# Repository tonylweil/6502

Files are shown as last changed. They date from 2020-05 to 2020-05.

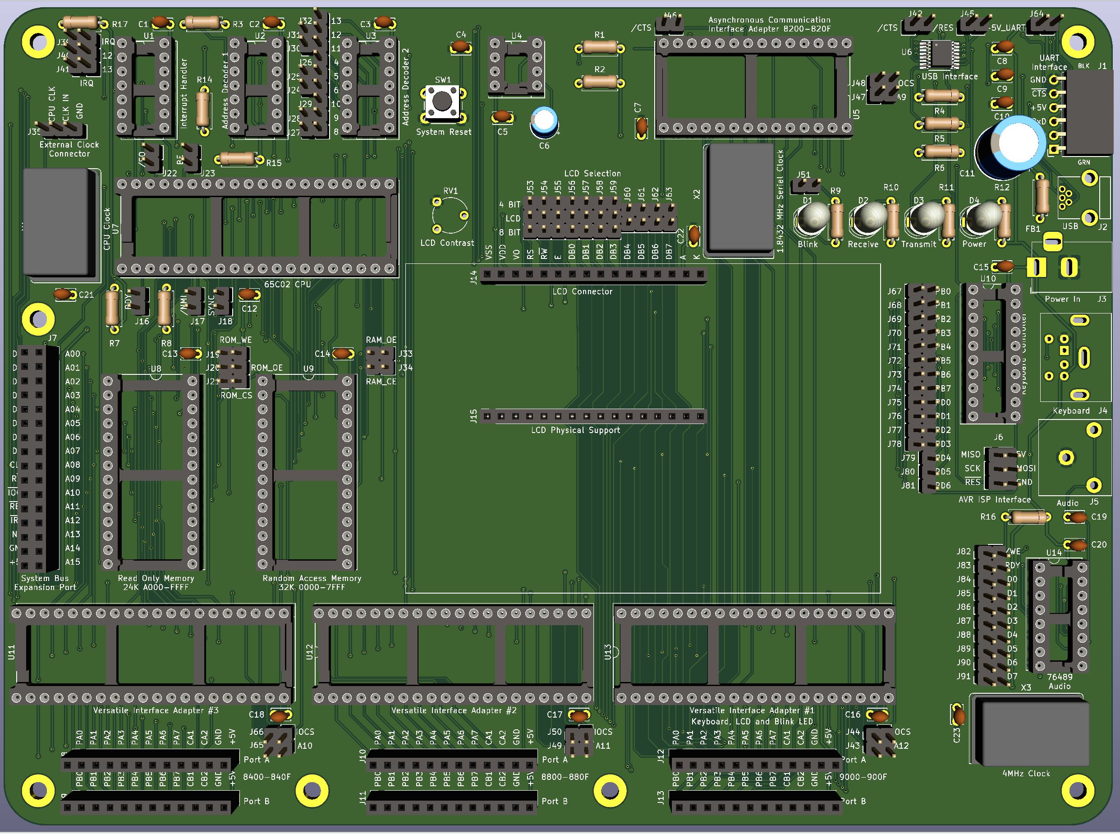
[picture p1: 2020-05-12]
Schematics/65C02_Computer/65C02_Computer.jpg

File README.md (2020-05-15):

# DB6502 V2 Tony Weil's Updates  - 5/15/2020

KiCad Schematics, Board files and Gerbers in the Schematics/65C02_Computer directory have been updated to v002. In general, changes were made to add a sound chip and third VIA. Many jumpers were added allowing disconnecting and reconfiguring many signals. You can use jumpers to switch between LCD 4bit and 8bit wiring. See schematic for all changes.

Changes include:

Added VIA 3 6522

Added 76489 sound chip,  to VIA2, 4Mhz oscillator and Audio Jack

Added Port A and Port B female pin headers for all 3 VIAs

Jumpers on LCD to switch between BE6502 8 bit and DB6502 4 bit, Moved LCD connector to center of board

Jumpers for CPU: BE, SO, NMI, READY, Sync

Jumpers for ROM: /OE, /CE and /WE lines

Jumpers for RAM: /OE and /CE 

Jumpers for VIA1-3 and ACIA, A9-A12 and IOCS Chip Select lines to change hardware addressing

Jumper to ground ACIA /CTS line and FT230x /CTS to support no hardware handshaking

Jumpers added to disconnect any existing connections to VIA1 (LCD and ATTINY) and VIA2 (76489 Sound chip)

Jumpers to be able to use extra NOR gates

FT230X /RES connected to VCCIO with jumper so it doesn't reset USB when computer is reset

Moved Expansion header from center to edge of board

Reorder FTDI header to match dongles, add jumper to disconnect 5v power, changed to horizontal pin header, move to board edge

Changed USB Micro connector to USB Mini THT. Much easier to solder!

Delete USB-B

Added more mounting holes near VIAs and Expansion header to help with plugging in cables

# ==============================

# V1 Readme

# DB6502 - Dawid Buchwald's 6502 Computer

This repository contains all the work in progress during my build of Ben Eater's inspired 6502 8-bit computer similar to typical machines of the early 1980s. If you haven't seen Ben's videos, I would strongly suggest you start there:

[Ben Eater's 6502 project](https://eater.net/6502)

As stated above, this build is not 100% compatible with what Ben had done - and for a reason, described in next section.

If I had to explain shortly "what it is", the answer would be: simple, yet easy to expand, 8-bit CPU based computer designed and built with one goal only: to use it as a learning and tinkering platform to understand how computers really work. You can use it for simple things like understanding buses, clock cycles, instruction execution, but it also demonstrates more complex concepts like interrupts, interfaces to external components and device handling. More on that below. Everything, hopefully, is simple enough to wrap your head around by one person in couple of weeks.

## Why build something different

[Ben's videos](https://www.youtube.com/playlist?list=PLowKtXNTBypFbtuVMUVXNR0z1mu7dp7eH) on 6502 computer are absolutely awesome - it's one of the best sources in the whole Internet explaining how any computer works. The build he introduced is probably sufficient for most of the things you might ever want to build, and yet I decided to deviate from his design.

The rationale behind this project is pretty simple - the best way to test your understanding of certain subject is to try to expand on what you have learned. You never know if you understood something until you test it by introducing changes to original design - and I used this approach in this project to learn a lot. It was my first proper electronics project, so I would like to apologize for any mistakes. If you think something is off or could have been done differently - please go ahead and raise issue for the repo! All improvements are welcome!

## Why would you bother using DB6502 instead of BE6502

Basically, it gives you almost all the flexibility of Ben's buid without the hassle of breadboard connections for the critical components. You can still run all of Ben's programs (using second VIA port), but the days of looking for loose wire between RAM and CPU are over :) You can, obviously, still experiment with peripherals and breadboard connections using extension port and second VIA.

On top of that you get additional features like extra screen (via onboard connector), keyboard for more versatile input and finally all-in-one serial over USB terminal. You also get easy to use software ready to be installed on the machine to jumpstart your tinkering. When using bootloader you don't even have to flash the EEPROM more than once!

**Important note:** All of the content here is, and always will be open source and free to use, and I don't intend to make any profit out of it. The only way I get anything at all (and it's only small commission to be used for future PCBWay orders) is when you order my boards from PCBWay using the links posted below, but you are welcome to grab these gerber files and order the boards from another provider, or even from PCBWay, just by uploading gerbers to your account, if you don't want me to get the commission :)

## What is different

Compared to Ben's 6502 build I introduced the following changes:

1. Added [automatic power-up reset circuitry](Schematics/README.md#automatic-power-on-reset),
2. Changed [address decoder logic](Schematics/README.md#address-decoder-change) (**very important from compatibility perspective**),
3. Changed [LCD interface](Schematics/README.md#lcd-interface-change) from 8-bit to 4-bit (**very important from compatibility perspective**),
4. Added [additional VIA chip](Schematics/README.md#extra-via-chip) to provide easy expansion of the system,
5. Added [ACIA chip for serial communication](Schematics/README.md#extra-acia-chip-for-serial-communication),
6. Added (**optional - more on that later**) [USB-UART interface](Schematics/README.md#extra-usb-uart-interface-chip) for easy connectivity with PC,
7. Added [PS/2 keyboard port and ATtiny4313-based keyboard controller](Schematics/README.md#ps2-keyboard-interface-and-attiny4313-based-controller) to provide proper replacement for five pushbuttons in Ben's design,
8. Added [expansion port](Schematics/README.md#expansion-port) (not really deviation from Ben's build, save for one detail - unlike Ben's build, my version can support various interrupt sources, including the expansion port),
9. Modified [clock module](Schematics/README.md#modified-clock-module) (external),
10. Changed [compilator from VASM to CC65](Schematics/README.md#migration-from-vasm-to-cc65),
11. Added [simple way to choose clock source](Schematics/README.md#clock-input).

You might be wondering if this means that you can't run Ben's programs on DB6502 - and the answer is **YES YOU CAN**. Indeed, some changes to the code are necessary, but thanks to the additional VIA chip and with some changes to the addressing mode you can run any program from Ben's videos. If you want to use LCD in 8-bit mode, you can also use the additional VIA for it, ignoring the built-in LCD connector.

By the way, the opposite is also true - **you can compile and run my programs on Ben's computer**. There are special compilation flags that enable usage of Ben's address decoder. I will describe this in more detail in software section.

Detailed description and rationale for each change is discussed in [Schematics README](Schematics/README.md).

## Getting started

Okay, so it should be pretty clear what this project is about, so how to start playing with it? That really depends on what you decide to do:

- Stick with BE6502 and just use subset of provided software (either to install it in EEPROM, or just use it as reference for your own hacking),
- Build your own breadboard design based on this one with any modifications you can think of,
- Order PCBs of DB6502, solder the components and run provided software to see how it works and get started with your own designs.

To start from scratch it's actually easiest to select last option - after some waiting you will end up having pretty solid base to extend your design on.

### Using provided software with BE6502

If you decide to go down that route, head straight to the `Software` folder, where you will find several programs either identical or similar to what Ben has shown in his videos, but built with much more versatile toolchain.

If you want to read more, go ahead and read [Software folder](Software/README.md) section. Make sure to check out the [building software](Software/README.md#building-software) subsection, as it explains how to compile programs to run on BE6502 directly.

### Build your own breadboard design

Maybe you have already started expanding on Ben's build, or maybe you are just considering it now. If you want to check out how I did certain things, jump right into `Schematics` [folder](Schematics/README.md), where you will find KiCAD projects for all the components used in this project. Obviously the most important one is the `65C02_Computer` project, but there are some additional goodies there.

**Please note:** This part is not very well documented, I have assumed that anybody willing to dig into these schematics already knows how to read them.

Most of the decisions made during the schematic design were explained above. Justification for anything not covered here can be probably found in the [invaluable 6502 primer](http://wilsonminesco.com/6502primer/).

### Using my PCB design

This will be explained in the most detail, obviously. Start with getting [the PCBs](Schematics/README.md#ordering-pcb). **Please note:** clock module is entirely optional, but really useful for single stepping or slow clocking required by Ben Eater's design of Arduino Mega based bus analyzer. As explained in number of places here, you can either order PCBs from PCBWay directly or use your manufacturer of choice - it should have no impact on the final result.

## What's in the repo

Everything, basically. Schematics of the 6502 board, modified clock module, address decoder and other circuits I built during the project. Arduino sketches I used for debugging and simple programs used to test different features.

And, last but not least, full set of sample programs to follow Ben's videos on DB6502 plus my own bootloader/OS. The last two things are coming soon :)

### `Arduino` folder

There are several sketches there, and their full description is available is [separate README](Arduino/README.md).

### `Datasheets` folder

All the datasheets I used when designing DB6502, attached for reference.

### `Schematics` folder

All the KiCAD schematics for the 6502 computer, modified clock module and several others:

- 65C02_Computer - main schematic, including PCB design for DB6502 computer,
- Clock_module - schematic for the modified clock module, including PCB design,
- 555_troubleshoot - schematic of circuit used in [troubleshooting of clock module monostable noise issue](https://www.reddit.com/r/beneater/comments/edp1ls/noise_issue_in_monostable_mode_of_ben_eaters/),
- Address_decoder_basic - schematic of Ben Eater's address decoder for 6502 project,
- Address_decoder_basic_v2 - slightly modified version of the above,
- Address_decoder_extended - schematic of my own address decoder, used in the DB6502 computer.

There is dedicated [README](Schematics/README.md) in the folder, containing all the build-related details.

### `Software` folder

This one is the most important folder, as it contains range of different programs to play with the 6502 computer. Large subset of this programs can be built for Ben Eater's version of the 6502 computer without any changes. Some of them, however, use features available only in DB6502, like ACIA or keyboard connector. These can still be ran on Ben Eater's 6502 computer, assuming that compatible hardware is added to it.

The `Software` folder is currently divided into four main parts:

- `build` - temporary folder where all the build artifacts are created, including ROM binaries to be uploaded to EEPROM,
- `common` - common sources: include files with common constants, sources with shared function, configuration files for different address decoder logic modes, shared makefile used by all projects and small python script to optimize size of loadable modules,
- `rom` - set of projects used to create various ROM images to follow Ben's videos, test different features of the board and **some day** complete operating system for the computer,
- `load` - set of project containing loadable modules. These can be uploaded at runtime, without the need to flash the EEPROM. Basic bootloader is required, obviously, and the usage instructions are provided below.

There is also one "master" makefile located directly in the `Software` folder - it will build all the projects in `rom` and `load` subfolders.

There is dedicated [README](Software/README.md) in the folder, containing all the software-related details.

## Credits

This project would not be possible if not inspiration, support and help from many, many people:

- [Ben Eater](https://eater.net) - his videos inspired me to learn all this,
- [Dirk Grappendorf](https://grappendorf.net) - awesome documentation of his own 6502 project,
- [Wilson Mines Co.](http://wilsonminesco.com) - the best source of 6502-related information,
- [Dane Creek Photography](https://github.com/danecreekphotography) - for all his support and test driving the project,
- [u/transistorykris](https://www.reddit.com/user/transitorykris/) - his [KrisOS](https://github.com/transitorykris/krisos) is a great inspiration for my own OS development,
- [r/beneater community](https://www.reddit.com/r/beneater/) - for all the great ideas, feedback, creative spirit and exceptional support.

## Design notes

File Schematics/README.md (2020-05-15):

# V2 Updates 5/15/2020

Address Mapping Table

The key takeway here is that when porting Ben's programs you have to use this "mapping table":
|Segment|BE6502 |DB6502 v1 |DB6502 v2 |Comment |
|---|---|---|---|---|
|RAM |0x0000-0x3fff|0x0000-0x7fff|0x0000-0x7fff| |
|VIA1 | |0x9000 |0x9000 |Connected to keyboard/LCD/blink LED in my build |
|VIA2 |0x6000 |0x8800 |0x8800|Can be used to run Ben's programs |
|VIA3 | |N/A| 0x8400 ||
|ACIA | |0x8400 | 0x8200 ||
|ROM |0x8000-0xffff|0xa000-0xffff|0xa000-0xffff|**First 8K are not accessible, but need to be burned to the chip**|

# V2 Part Ordering
You can create a Digikey BOM by going to this link:

https://www.digikey.com/BOM/Create/CreateSharedBom?bomId=8248210

Other parts you can't buy from Digikey:

| Reference | Type | Value | Description | Vendor | Part Number |
| --- | --- | --- | --- | --- | --- |
| U5 See Note | IC  | 65C51N | ACIA | Mouser | [W65C51N6TPG–14](https://www.mouser.com/ProductDetail/western-design-center-wdc/w65c51n6tpg-14/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) |
| U5 See Note | IC  | R6551 S6551 | ACIA | Jameco | [6551](https://www.jameco.com/shop/ProductDisplay?catalogId=10001&langId=-1&storeId=10001&productId=43318) |
| U7 | IC  | 65C02 | CPU | Jameco | [W65C02S6TPG-14](https://www.jameco.com/shop/ProductDisplay?productId=2143638) |
| U11, U12, U13 | IC  | 65C22S | VIA | Jameco | [W65C22S6TPG-14](https://www.jameco.com/shop/ProductDisplay?productId=2143591) |
| U14 | IC  | SN76489AN | Audio Chip | Twisty Wrist Arcade  | [SN76489AN](https://www.twistywristarcade.com/sound-processors/1120-sn76489.html)  |

(Copied from v1 notes)

Note: Important note about the ACIA chip: There are basically two types of chips that can be used. 
1) Modern, rated to higher frequencies WDC65C51 and older, 
2) Rockwell 6551P chips, rated only for 1MHz. 

The problem with former is that there is a bug with interrupt handling on transmit operation - both IRQ and status flag polling fail, you have to implement dead loop to wait long enough for the byte to be transmitted. Latter chip is probably no longer manufactured, but can be purchased online from Chinese sellers - these are cheap, but not all of them work correctly, so get more than one to be safe. For me the second chip worked correctly and both polling and IRQ-based transmit work as expected.

# ====================================
# V1 Readme

# 6502 system schematics

This documentation provides all the information regarding my variant of BE6502 computer:

- [Differences between the builds](#deviations-from-ben-eaters-design),
- [Instruction to order the PCBs](#ordering-pcb),
- [Getting started with the PCB](#building-pcb).

## Deviations from Ben Eater's design

This section describes details of each deviation from original BE6502 design.

### Automatic power-on reset

More of a cosmetic thing, but I liked the idea of computer running automatic reset on power-up. The added appeal was that the circuitry is actually copied from the original C64, which makes it instantly 1000x cooler :) You can read more on that here:
[Dirk Grappendorf's 6502 project - RESET](https://www.grappendorf.net/projects/6502-home-computer/reset-circuit.html)

As a side note - I would strongly recommend anybody interested to read about Dirk's project, he has plenty of great insight there!

### Address decoder change

This one was my first _real_ change as in it was _mine_. As Ben explained in his video, there are many ways to handle address decoding logic and he opted for model with 16K RAM, 16K I/O shadow and 32K ROM. He does note that it's a bit of a waste, but given the simplicity of the project it should not be a problem - and he is absolutely right.

That being said, I wanted more for my build. I knew I wanted to be able to load programs into my computer and I wanted to ensure that I provide user with as much RAM as possible. At the same time, I wanted to save some space on more optimized I/O shadow segment. And, most importantly, I wanted to test my understanding of how address decoding works. As stated above, the best way to learn is to change and test your hypothesis. If you want to learn more, I posted thread on [Reddit](https://www.reddit.com/r/beneater/comments/ej3lqi/65c02_address_decoder_for_32k_ram_24k_rom_and_2/) explaining what I did, how I did that and why I know it works. My build provides 32K RAM, 8K I/O shadow (for up to 11 devices), 24K ROM.

The key takeway here is that when porting Ben's programs you have to use this "mapping table":
|Segment|BE6502 |DB6502 |Comment |
|---|---|---|---|
|RAM |0x0000-0x3fff|0x0000-0x7fff| |
|VIA1 | |0x9000 |Connected to keyboard/LCD/blink LED in my build |
|VIA2 |0x6000 |0x8800 |Can be used to run Ben's programs |
|ACIA | |0x8400 | |
|ROM |0x8000-0xffff|0xa000-0xffff|**First 8K are not accessible, but need to be burned to the chip**|

Simplest possible example - [Blink LED example](https://eater.net/downloads/makerom.py) from Ben's page:

```python
#
# Please see this video for details:
# https://www.youtube.com/watch?v=yl8vPW5hydQ
#
code = bytearray([
  0xa9, 0xff,         # lda #$ff
  0x8d, 0x02, 0x60,   # sta $6002

  0xa9, 0x55,         # lda #$55
  0x8d, 0x00, 0x60,   # sta $6000

  0xa9, 0xaa,         # lda #$aa
  0x8d, 0x00, 0x60,   # sta $6000

  0x4c, 0x05, 0x80,   # jmp $8005
  ])

rom = code + bytearray([0xea] * (32768 - len(code)))

rom[0x7ffc] = 0x00
rom[0x7ffd] = 0x80

with open("rom.bin", "wb") as out_file:
  out_file.write(rom)
```

The same program to run on my build:

```python
#
# Please see this video for details:
# https://www.youtube.com/watch?v=yl8vPW5hydQ
#
code = bytearray([
  0xa9, 0xff,         # lda #$ff
  0x8d, 0x02, 0x88,   # sta $8802 # MODIFIED HERE - use different VIA address

  0xa9, 0x55,         # lda #$55
  0x8d, 0x00, 0x88,   # sta $8800 # MODIFIED HERE - use different VIA address

  0xa9, 0xaa,         # lda #$aa
  0x8d, 0x00, 0x88,   # sta $8800 # MODIFIED HERE - use different VIA address

  0x4c, 0x05, 0xa0,   # jmp $a005 # MODIFIED HERE - different code start address, so different jump target
  ])

# MODIFIED BELOW - first 8KB of ROM are not really used, but need to be filled out; actual ROM starts at address
# 0xa000 and is of 24KB length
rom = bytearray([0xea] * 8192) + code + bytearray([0xea] * (24576 - len(code)))

rom[0x7ffc] = 0x00
rom[0x7ffd] = 0xa0 # MODIFIED HERE - different code start address

with open("rom.bin", "wb") as out_file:
  out_file.write(rom)
```

### LCD interface change

One of the silly things I decided to do, was to save pins on the first VIA chip and I decided on the following mapping:

| Port  | Pins | Connection |
| ----- | --- | --- |
| PORTA | CA1,CA2 | Keyboard controller read handshake - for IRQ based communication with keyboard controller |
| PORTA | D0-D7 | Keyboard controller data line - for transferring ASCII scancodes of pressed characters |
| PORTB | CB1,CB2 | Not used, disconnected |
| PORTB | D0 | Blink LED - to be used as the Arduino onboard LED, for easy debugging |
| PORTB | D1-D3 | LCD control signals (register select, R/W, enable) |
| PORTB | D4-D7 | LCD data signals for 4-bit operation |

Afterwards it turned out that 4-bit operation is actually bit more complicated that 8-bit, and it breaks compatibility with Ben's programs. My best advice, if you want to run Ben's LCD programs on this build, is to use the second VIA port and 8-bit interface.

If you want to use onboard LCD conector and 4-bit interface it is suggested to use the code I supplied in this repo. It has all the data communication routines for LCD 4-bit operation tested and ready to go.

### Extra VIA chip

This one increases cost of the build, but in the end you have the whole chip to yourself, so you can hack whatever contraptions you can think of :)

This extra VIA chip can be also used to run Ben's programs, but you have to remember to update addressing mode.

### Extra ACIA chip for serial communication

This one is really important - thanks to ACIA chip you can actually forget about LCD and keyboard altogether, and all the input/output can be handled by the serial port. This also allows you to run programs that are loaded in runtime, over the serial line, making the ROM flashing no longer necessary. Obviously, there is a bootloader program required in ROM and one will be provided in this repo for your use shortly.

Currently my software supports only Rockwell R6551P chips and it uses fully asynchronous, buffered and IRQ driven send/receive operations. In future I plan to add support for WDC65C51 chips, but this requires change in source code to blocking send operation. Not a biggie, just not at the top of my priorities now. More on the ACIA chips below, in the PCB BOM section.

### Extra USB->UART interface chip

When I designed PCB for DB6502, I had one goal in mind: it must be possible to solder it with THT-only components. So, if you don't want to play with SMD soldering (which, admittably, is much easier that it seems), you can completely skip this component and connect serial over one of many UART->USB adapters. The same goes for the Micro-USB port - you can skip it, and use only USB-B port for power. Your call.

If you do decide to use FT230X chip onboard, you will have a 6502 computer that requires only USB cable - simply plug it in your PC, connect using serial terminal and you are good to go, nothing else needed. Power consumption is well below USB limits, even with LCD and external keyboard connected.

### PS/2 Keyboard interface and ATtiny4313 based controller

This was a bit of an overkill with the serial port addition, but I wanted DB6502 to be versatile and enable operation without PC connected.

Software to be uploaded to ATtiny is also provided in this repo and discussed in detail in dedicated section. You can either program the chip away from the board or use the included AVR ISP interface. I have successfully used USBASP programmer onboard, and since the reset lines between ATtiny and CPU/VIA/ACIA/FT230X are all connected, upload operation simply resets the whole computer without any risk for running programs. Pretty neat, that one :)

### Expansion port

The main purpose is to enable easy connection of Arduino-based debugger as used in Ben's videos. Everyone who managed to build the 6502 kit on breadboard knows how difficult it is to manage these connections and prevent them from unplugging system bus wires. In my build there is dedicated connector with several other options.

Beside address bus, data bus, clock and R/W signals, you will also find reset line (can be pulled low for external reset), IRQ input line (can be pulled low to signal interrupt, but can't be used to intercept system IRQs) and IOCS signal from address decoder indicating that CPU is now using address in I/O shadow range.

IOCS line can be used to add additional chips like ACIA or VIA via expansion port. VIA1 is selected using IOCS and A12 line (address 0b1001xxxxxxxxxxxx), VIA2 is selected using IOCS and A11 line (address 0b100x1xxxxxxxxxx), ACIA using IOCS and A10 line (address 0b100xx1xxxxxxxxxx), and you can access external I/O chips using addresses like IOCS and A9 for example (address 0b100xxx1xxxxxxxx). As you can see, it enables up to 8 external I/O chips (last two lines A0/A1 for register select) :)

### Modified clock module

I have also modified Ben's design of clock module used in both [8-bit breadboard computer](https://eater.net/8bit) and in [6502 computer](https://eater.net/6502). The reason here was pretty similar - modification introduced to validate own understanding of the original design. There was another thing, though - contents of my kit were not aligned with Ben's design (wrong kind of switch) and the design itself had serious flaw. Details of both of these things have been explained in detail [here](https://www.reddit.com/r/beneater/comments/eai6ke/issue_with_clock_kit_and_possible_solution_with/) and [here](https://www.reddit.com/r/beneater/comments/edp1ls/noise_issue_in_monostable_mode_of_ben_eaters/).

### Migration from VASM to CC65

As much as I liked VASM for small, simple projects, it became quite cumbersome to use when I wanted to introduce different addressing models. CC65 is basically much better compiler for anything 65(C)02 :)

If time allows, I will also provide special versions of Ben's programs written for VASM, but targeted for my own build.

### Clock input

Clock signal can be provided in one of three ways:

1. Use onboard 1MHz oscillator - simply put jumper on J1 connector two leftmost pins,
2. Use external clock module - remove the jumper from J1 connector, and connect clock signal to middle pin,
3. Use expansion port - remove jumper from J1 connector and provide clock signal via CLK pin of the expansion port.

Last option will be used in (planned currently) custom debugger board.

## Ordering PCB

[First revision of PCBs](https://github.com/dbuchwald/6502/releases/tag/pcb-v001) have been released (one for modified clock module and one for the computer itself). PCBs can be ordered here (**please note: I get small commission in coupons from PCBWay when ordering using these links**. If you don't want that to happen, please download gerbers from the GitHub rulease page and order directly via PCBWay home page):

[PCBWay Shared Projects - 65C02 Hobby Computer](https://www.pcbway.com/project/shareproject/65C02_Hobby_Computer.html)

[PCBWay Shared Projects - Clock Module](https://www.pcbway.com/project/shareproject/Modified_version_of_Clock_Module_by_Ben_Eater_s.html)

### 65C02 Computer Bill Of Materials

The following components are required for DB65C02 Computer

| Reference | Type | Value | Description | Jameco | DigiKey |
| --- | --- | --- | --- | --- | --- |
| C1 | Unpolarized Capacitor  | 100 nF | Disk, 2.5mm raster | [151116](https://www.jameco.com/shop/ProductDisplay?productId=151116) | [399-4151-ND](https://www.digikey.com/products/en?keywords=399-4151-ND) |
| C2 | Unpolarized Capacitor  | 100 nF | Disk, 2.5mm raster | [151116](https://www.jameco.com/shop/ProductDisplay?productId=151116) | [399-4151-ND](https://www.digikey.com/products/en?keywords=399-4151-ND) |
| C3 | Unpolarized Capacitor  | 100 nF | Disk, 2.5mm raster | [151116](https://www.jameco.com/shop/ProductDisplay?productId=151116) | [399-4151-ND](https://www.digikey.com/products/en?keywords=399-4151-ND) |
| C4 | Unpolarized Capacitor  | 100 nF | Disk, 2.5mm raster | [151116](https://www.jameco.com/shop/ProductDisplay?productId=151116) | [399-4151-ND](https://www.digikey.com/products/en?keywords=399-4151-ND) |
| C5 | Unpolarized Capacitor  | 100 nF | Disk, 2.5mm raster | [151116](https://www.jameco.com/shop/ProductDisplay?productId=151116) | [399-4151-ND](https://www.digikey.com/products/en?keywords=399-4151-ND) |
| C6 | Polarized Capacitor | 10 uF | Tube, 2.5mm raster, 5mm diameter | [330692](https://www.jameco.com/shop/ProductDisplay?productId=330692) | [1189-2322-ND](https://www.digikey.com/products/en?keywords=1189-2322-ND) |
| C7 | Unpolarized Capacitor  | 100 nF | Disk, 2.5mm raster | [151116](https://www.jameco.com/shop/ProductDisplay?productId=151116) | [399-4151-ND](https://www.digikey.com/products/en?keywords=399-4151-ND) |
| C8 | Unpolarized Capacitor  | 10 nF | Disk, 2.5mm raster | | [399-4150-ND](https://www.digikey.com/products/en?keywords=399-4150-ND) |
| C9 | Unpolarized Capacitor  | 47 pF | Disk, 2.5mm raster | [2300831](https://www.jameco.com/shop/ProductDisplay?productId=2300831) | [399-9737-ND](https://www.digikey.com/products/en?keywords=399-9737-ND) |
| C10 | Unpolarized Capacitor  | 47 pF | Disk, 2.5mm raster | [2300831](https://www.jameco.com/shop/ProductDisplay?productId=2300831) | [399-9737-ND](https://www.digikey.com/products/en?keywords=399-9737-ND) |
| C11 | Polarized Capacitor | 1000 uF | Tube, 5mm raster, 10mm diameter | [330722](https://www.jameco.com/shop/ProductDisplay?productId=330722) | [1189-1745-ND](https://www.digikey.com/products/en?keywords=1189-1745-ND) |
| C12 | Unpolarized Capacitor  | 100 nF | Disk, 2.5mm raster | [151116](https://www.jameco.com/shop/ProductDisplay?productId=151116) | [399-4151-ND](https://www.digikey.com/products/en?keywords=399-4151-ND) |
| C13 | Unpolarized Capacitor  | 100 nF | Disk, 2.5mm raster | [151116](https://www.jameco.com/shop/ProductDisplay?productId=151116) | [399-4151-ND](https://www.digikey.com/products/en?keywords=399-4151-ND) |
| C14 | Unpolarized Capacitor  | 100 nF | Disk, 2.5mm raster | [151116](https://www.jameco.com/shop/ProductDisplay?productId=151116) | [399-4151-ND](https://www.digikey.com/products/en?keywords=399-4151-ND) |
| C15 | Unpolarized Capacitor  | 100 nF | Disk, 2.5mm raster | [151116](https://www.jameco.com/shop/ProductDisplay?productId=151116) | [399-4151-ND](https://www.digikey.com/products/en?keywords=399-4151-ND) |
| C16 | Unpolarized Capacitor  | 100 nF | Disk, 2.5mm raster | [151116](https://www.jameco.com/shop/ProductDisplay?productId=151116) | [399-4151-ND](https://www.digikey.com/products/en?keywords=399-4151-ND) |
| C17 | Unpolarized Capacitor  | 100 nF | Disk, 2.5mm raster | [151116](https://www.jameco.com/shop/ProductDisplay?productId=151116) | [399-4151-ND](https://www.digikey.com/products/en?keywords=399-4151-ND) |
| D1 | LED | Green | 5mm diameter (PWR) | [2279199](https://www.jameco.com/shop/ProductDisplay?productId=2279199) | [754-1263-ND](https://www.digikey.com/products/en?keywords=754-1263-ND) |
| D2 | LED | Red | 5mm diameter (TX) | [333973](https://www.jameco.com/shop/ProductDisplay?productId=333973) | [754-1264-ND](https://www.digikey.com/products/en?keywords=754-1264-ND) |
| D3 | LED | Green | 5mm diameter (RX) | [2279199](https://www.jameco.com/shop/ProductDisplay?productId=2279199) | [754-1263-ND](https://www.digikey.com/products/en?keywords=754-1263-ND) |
| D4 | LED | Red | 5mm diameter (BLINK) | [333973](https://www.jameco.com/shop/ProductDisplay?productId=333973) | [754-1264-ND](https://www.digikey.com/products/en?keywords=754-1264-ND) |
| FB1 | Ferrite bead small | | | [1844580](https://www.jameco.com/shop/ProductDisplay?productId=1844580) | [490-10997-ND](https://www.digikey.com/products/en?keywords=490-10997-ND) |
| J1 | Pin header 3x1 | | 2.54mm raster | | [2057-PH1-03-UA-ND](https://www.digikey.com/products/en?keywords=2057-PH1-03-UA-ND) |
| J2 | Female pin header 6x1  | | 2.54mm raster | | [S7004-ND](https://www.digikey.com/products/en?keywords=S7004-ND) |
| J3 | USB B Micro | | Molex 105017-0001 | | [WM1399CT-ND](https://www.digikey.com/products/en?keywords=WM1399CT-ND) |
| J4 | USB B | | Standard THT horizontal USB B port | [2096245](https://www.jameco.com/shop/ProductDisplay?productId=2096245) | [2057-USB-B-S-RA-ND](https://www.digikey.com/products/en?keywords=2057-USB-B-S-RA-ND) |
| J5 | Barrel Jack | | Standard power input 2.1/5.5 | [101178](https://www.jameco.com/shop/ProductDisplay?productId=101178) | |
| J6 | Mini-Din-6 | | Standard THT PS/2 Keyboard port | [119475](https://www.jameco.com/shop/ProductDisplay?productId=119475) | [CP-2260-ND](https://www.digikey.com/products/en?keywords=CP-2260-ND) |
| J7 | Female pin header 16x2 | | 2.54mm raster | | [S7049-ND](https://www.digikey.com/products/en?keywords=S7049-ND) |
| J8 | Pin header 3x2 | | AVR ISP 2.54mm raster | | [609-3234-ND](https://www.digikey.com/products/en?keywords=609-3234-ND) |
| J9 | Pin header 12x1 | | 2.54mm raster | | [2057-PH1-12-UA-ND](https://www.digikey.com/products/en?keywords=2057-PH1-12-UA-ND) |
| J10 | Pin header 12x1 | | 2.54mm raster | | [2057-PH1-12-UA-ND](https://www.digikey.com/products/en?keywords=2057-PH1-12-UA-ND) |
| J11 | Female pin header 16x1 | | 2.54mm raster | | [S7049-ND](https://www.digikey.com/products/en?keywords=S7049-ND) |
| R1 | Resistor | 1M | 1/4 watt | [691585](https://www.jameco.com/shop/ProductDisplay?productId=691585) | |
| R2 | Resistor | 47K | 1/4 watt | [691260](https://www.jameco.com/shop/ProductDisplay?productId=691260) | |
| R3 | Resistor | 10K | 1/4 watt | [691104](https://www.jameco.com/shop/ProductDisplay?productId=691104) | |
| R4 | Resistor | 27 | 1/4 watt | [690486](https://www.jameco.com/shop/ProductDisplay?productId=690486) | |
| R5 | Resistor | 27 | 1/4 watt | [690486](https://www.jameco.com/shop/ProductDisplay?productId=690486) | |
| R6 | Resistor | 4K7 | 1/4 watt | [691260](https://www.jameco.com/shop/ProductDisplay?productId=691260) | |
| R7 | Resistor | 4K7 | 1/4 watt | [691260](https://www.jameco.com/shop/ProductDisplay?productId=691260) | |
| R8 | Resistor | 4K7 | 1/4 watt | [691260](https://www.jameco.com/shop/ProductDisplay?productId=691260) | |
| R9 | Resistor | 220 | 1/4 watt | [690700](https://www.jameco.com/shop/ProductDisplay?productId=690700) | |
| R10 | Resistor | 220 | 1/4 watt | [690700](https://www.jameco.com/shop/ProductDisplay?productId=690700) | |
| R11 | Resistor | 220 | 1/4 watt | [690700](https://www.jameco.com/shop/ProductDisplay?productId=690700) | |
| R12 | Resistor | 220 | 1/4 watt | [690700](https://www.jameco.com/shop/ProductDisplay?productId=690700) | |
| R13 | Resistor | 4K7 | 1/4 watt | [691260](https://www.jameco.com/shop/ProductDisplay?productId=691260) | |
| RV1 | Potentiometer | 10K | Piher PT10-LV10-103 | | [1993-1116-ND](https://www.digikey.com/products/en?keywords=1993-1116-ND) |
| SW1 | Pushbutton | | Standard 6mm THT pushbutton | [149948](https://www.jameco.com/shop/ProductDisplay?productId=149948) | |
| U1 | IC | 74HC21 | | [2285255](https://www.jameco.com/shop/ProductDisplay?productId=2285255) | [296-8266-5-ND](https://www.digikey.com/products/en?keywords=296-8266-5-ND) |
| U1 | Socket | 14-pin | | [51626](https://www.jameco.com/shop/ProductDisplay?productId=51626) | [ED90048-ND](https://www.digikey.com/products/en?keywords=ED90048-ND) |
| U2 | IC | 74HC00 | | [45161](https://www.jameco.com/shop/ProductDisplay?productId=45161) | [296-1563-5-ND](https://www.digikey.com/products/en?keywords=296-1563-5-ND) |
| U2 | Socket | 14-pin | | [51626](https://www.jameco.com/shop/ProductDisplay?productId=51626) | [ED90048-ND](https://www.digikey.com/products/en?keywords=ED90048-ND) |
| U3 | IC | 74HC02 | | [45188](https://www.jameco.com/shop/ProductDisplay?productId=45188) | [296-1564-5-ND](https://www.digikey.com/products/en?keywords=296-1564-5-ND) |
| U3 | Socket | 14-pin | | [51626](https://www.jameco.com/shop/ProductDisplay?productId=51626) | [ED90048-ND](https://www.digikey.com/products/en?keywords=ED90048-ND) |
| U4 | IC | NE555 | | [27422](https://www.jameco.com/shop/ProductDisplay?productId=27422) | [296-NE555P-ND](https://www.digikey.com/products/en?keywords=296-NE555P-ND) |
| U1 | Socket | 8-pin | | [51626](https://www.jameco.com/shop/ProductDisplay?productId=51626) | [ED90048-ND](https://www.digikey.com/products/en?keywords=ED90048-ND) |
| U5 | IC | 6551 | ACIA chip, see notes below | [43318](https://www.jameco.com/shop/ProductDisplay?productId=43318) | |
| U6 | IC | FT230XS | | | [768-1135-1-ND](https://www.digikey.com/products/en?keywords=768-1135-1-ND) |
| U7 | IC | 65C02S | | [2143638](https://www.jameco.com/shop/ProductDisplay?productId=2143638) | |
| U7 | Socket | 40-pin | | [41136](https://www.jameco.com/shop/ProductDisplay?productId=41136) | [ED90059-ND](https://www.digikey.com/products/en?keywords=ED90059-ND) |
| U8 | IC | 28C256 | | [74843](https://www.jameco.com/shop/ProductDisplay?productId=74843) | [AT28C256-15PU-ND](https://www.digikey.com/products/en?keywords=AT28C256-15PU-ND) |
| U8 | Socket | 28-pin | Order two | [2289583](https://www.jameco.com/shop/ProductDisplay?productId=2289583) | [ED90520-ND](https://www.digikey.com/products/en?keywords=ED90520-ND) |
| U9 | IC | 62256 | | [82472](https://www.jameco.com/shop/ProductDisplay?productId=82472) | [1450-1480-ND](https://www.digikey.com/products/en?keywords=1450-1480-ND) |
| U9 | Socket | 28-pin | | [2289583](https://www.jameco.com/shop/ProductDisplay?productId=2289583) | [ED90520-ND](https://www.digikey.com/products/en?keywords=ED90520-ND) |
| U10 | IC | ATtiny4313-PU | Add socket | | [ATTINY4313-PU-ND](https://www.digikey.com/products/en?keywords=ATTINY4313-PU-ND) |
| U10 | Socket | 20-pin | | [38623](https://www.jameco.com/shop/ProductDisplay?productId=38623) | [ED90036-ND](https://www.digikey.com/products/en?keywords=ED90036-ND) |
| U11 | IC | 65C22S | | [2143591](https://www.jameco.com/shop/ProductDisplay?productId=2143591) | |
| U11 | Socket | 40-pin | | [41136](https://www.jameco.com/shop/ProductDisplay?productId=41136) | [ED90059-ND](https://www.digikey.com/products/en?keywords=ED90059-ND) |
| U12 | IC | 65C22S | | [2143591](https://www.jameco.com/shop/ProductDisplay?productId=2143591) | |
| U12 | Socket | 40-pin | | [41136](https://www.jameco.com/shop/ProductDisplay?productId=41136) | [ED90059-ND](https://www.digikey.com/products/en?keywords=ED90059-ND) |
| X1 | Crystal Oscillator | 1MHz | | [27861](https://www.jameco.com/shop/ProductDisplay?productId=27861) | [X937-ND](https://www.digikey.com/products/en?keywords=X937-ND) |
| X2 | Crystal Oscillator | 1.8432MHz | | [27879](https://www.jameco.com/shop/ProductDisplay?productId=27879) | [X939-ND](https://www.digikey.com/products/en?keywords=X939-ND) |

[
_Important note about the ACIA chip_: There are basically two types of chips that can be used. Modern, rated to higher frequencies WDC65C51 and older, Rockwell 6551P chips, rated only for 1MHz. The problem with former is that there is a bug with interrupt handling on transmit operation - both IRQ and status flag polling fail, you have to implement dead loop to wait long enough for the byte to be transmitted. Latter chip is probably no longer manufactured, but can be purchased online from Chinese sellers - these are cheap, but not all of them work correctly, so get more than one to be safe. For me the second chip worked correctly and both polling and IRQ-based transmit work as expected.

_Notes about the resistors_: Jameco sells a [resistor assortment](https://www.jameco.com/z/ASST27-R-Resistor-Assortment-1-4-Watt-5-2700-Pieces_10664.html) that includes all the 1/4 watt resistors required for this project except for 27 ohm and will stock you with resistors for many electronics projects going forward.

### Clock Module Bill Of Materials

The following components are required for building Clock Module

| Reference | Type | Value  | Description | Jameco | DigiKey |
| --- | --- | --- | --- | --- | --- |
| C1 | Polarized capacitor | 1 uF | 2.5mm raster, 5mm diameter | [330431](https://www.jameco.com/shop/ProductDisplay?productId=330431) | [1189-1401-ND](https://www.digikey.com/products/en?keywords=1189-1401-ND) |
| C2 | Polarized capacitor | 1 uF | 2.5mm raster, 5mm diameter | [330431](https://www.jameco.com/shop/ProductDisplay?productId=330431) | [1189-1401-ND](https://www.digikey.com/products/en?keywords=1189-1401-ND) |
| C3 | Unpolarized capacitor | 10 nF  | 2.5mm raster | | [399-4150-ND](https://www.digikey.com/products/en?keywords=399-4150-ND) |
| C4 | Unpolarized capacitor | 100 nF | 2.5mm raster | [151116](https://www.jameco.com/shop/ProductDisplay?productId=151116) | [399-4151-ND](https://www.digikey.com/products/en?keywords=399-4151-ND) |
| C5 | Unpolarized capacitor | 100 nF | 2.5mm raster | [151116](https://www.jameco.com/shop/ProductDisplay?productId=151116) | [399-4151-ND](https://www.digikey.com/products/en?keywords=399-4151-ND) |
| C6 | Unpolarized capacitor | 100 nF | 2.5mm raster | [151116](https://www.jameco.com/shop/ProductDisplay?productId=151116) | [399-4151-ND](https://www.digikey.com/products/en?keywords=399-4151-ND) |
| C7 | Unpolarized capacitor | 100 nF | 2.5mm raster | [151116](https://www.jameco.com/shop/ProductDisplay?productId=151116) | [399-4151-ND](https://www.digikey.com/products/en?keywords=399-4151-ND) |
| C8 | Unpolarized capacitor | 100 nF | 2.5mm raster | [151116](https://www.jameco.com/shop/ProductDisplay?productId=151116) | [399-4151-ND](https://www.digikey.com/products/en?keywords=399-4151-ND) |
| C9 | Polarized capacitor | 1 uF | 2.5mm raster, 5mm diameter | [330431](https://www.jameco.com/shop/ProductDisplay?productId=330431) | [1189-1401-ND](https://www.digikey.com/products/en?keywords=1189-1401-ND) |
| D1 | LED | Yellow | 5mm diameter (Automatic tick) | [34825](https://www.jameco.com/shop/ProductDisplay?productId=34825) | [754-1284-ND](https://www.digikey.com/products/en?keywords=754-1284-ND) |
| D2 | LED | Red | 5mm diameter (Manual mode) | [333973](https://www.jameco.com/shop/ProductDisplay?productId=333973) | [754-1264-ND](https://www.digikey.com/products/en?keywords=754-1264-ND) |
| D3 | LED | Green  | 5mm diameter (Automatic mode) | [2279199](https://www.jameco.com/shop/ProductDisplay?productId=2279199) | [754-1263-ND](https://www.digikey.com/products/en?keywords=754-1263-ND) |
| D4 | LED | Yellow | 5mm diameter (Manual tick) | [34825](https://www.jameco.com/shop/ProductDisplay?productId=34825) | [754-1284-ND](https://www.digikey.com/products/en?keywords=754-1284-ND) |
| D5 | LED | Blue | 5mm diameter (Output tick) | [2234071](https://www.jameco.com/shop/ProductDisplay?productId=2234071) | [754-1489-ND](https://www.digikey.com/products/en?keywords=754-1489-ND) |
| J1 | Female pin header 6x1 | | 2.54mm raster | | [S7004-ND](https://www.digikey.com/products/en?keywords=S7004-ND) |
| J2 | Barrel Jack | | Standard power input 2.1/5.5  | [101178](https://www.jameco.com/shop/ProductDisplay?productId=101178) | |
| R1 | Resistor | 1K | 1/4 watt | [690865](https://www.jameco.com/shop/ProductDisplay?productId=690865) | |
| R2 | Resistor | 1K | 1/4 watt | [690865](https://www.jameco.com/shop/ProductDisplay?productId=690865) | |
| R3 | Resistor | 1K | 1/4 watt | [690865](https://www.jameco.com/shop/ProductDisplay?productId=690865) | |
| R4 | Resistor | 100K | 1/4 watt | [691340](https://www.jameco.com/shop/ProductDisplay?productId=691340) | |
| R5 | Resistor | 10K | 1/4 watt | [691260](https://www.jameco.com/shop/ProductDisplay?productId=691260) | |
| R6 | Resistor | 1K | 1/4 watt | [690865](https://www.jameco.com/shop/ProductDisplay?productId=690865) | |
| R7 | Resistor | 10K | 1/4 watt | [691260](https://www.jameco.com/shop/ProductDisplay?productId=691260) | |
| R8 | Resistor | 1K | 1/4 watt | [690865](https://www.jameco.com/shop/ProductDisplay?productId=690865) | |
| R9 | Resistor | 1M | 1/4 watt | [691585](https://www.jameco.com/shop/ProductDisplay?productId=691585) | |
| R10 | Resistor | 220 | 1/4 watt | [690700](https://www.jameco.com/shop/ProductDisplay?productId=690700) | |
| R11 | Resistor | 220 | 1/4 watt | [690700](https://www.jameco.com/shop/ProductDisplay?productId=690700) | |
| R12 | Resistor | 220 | 1/4 watt | [690700](https://www.jameco.com/shop/ProductDisplay?productId=690700) | |
| R13 | Resistor | 220 | 1/4 watt | [690700](https://www.jameco.com/shop/ProductDisplay?productId=690700) | |
| R14 | Resistor | 220 | 1/4 watt | [690700](https://www.jameco.com/shop/ProductDisplay?productId=690700) | |
| R15 | Resistor | 1K | 1/4 watt | [690865](https://www.jameco.com/shop/ProductDisplay?productId=690865) | |
| RV1 | Potentiometer | 1M | Piher PT10-LV10-105 | | [1993-1117-ND](https://www.digikey.com/products/en?keywords=1993-1117-ND) |
| SW1 | Pushbutton | | Standard 6mm THT pushbutton | [149948](https://www.jameco.com/shop/ProductDisplay?productId=149948) | |
| SW2 | Pushbutton | | Standard 6mm THT pushbutton | [149948](https://www.jameco.com/shop/ProductDisplay?productId=149948) | |
| U1 | IC | NE555  | | [27422](https://www.jameco.com/shop/ProductDisplay?productId=27422) | [296-NE555P-ND](https://www.digikey.com/products/en?keywords=296-NE555P-ND) |
| U1 | Socket | 8-pin  | | [51626](https://www.jameco.com/shop/ProductDisplay?productId=51626) | [ED90048-ND](https://www.digikey.com/products/en?keywords=ED90048-ND) |
| U2 | IC | NE555  | | [27422](https://www.jameco.com/shop/ProductDisplay?productId=27422) | [296-NE555P-ND](https://www.digikey.com/products/en?keywords=296-NE555P-ND) |
| U2 | Socket | 8-pin  | | [51626](https://www.jameco.com/shop/ProductDisplay?productId=51626) | [ED90048-ND](https://www.digikey.com/products/en?keywords=ED90048-ND) |
| U3 | IC | NE555  | | [27422](https://www.jameco.com/shop/ProductDisplay?productId=27422) | [296-NE555P-ND](https://www.digikey.com/products/en?keywords=296-NE555P-ND) |
| U3 | Socket | 8-pin  | | [51626](https://www.jameco.com/shop/ProductDisplay?productId=51626) | [ED90048-ND](https://www.digikey.com/products/en?keywords=ED90048-ND) |
| U4 | IC | 74LS04 | | [46316](https://www.jameco.com/shop/ProductDisplay?productId=46316) | [296-1629-5-ND](https://www.digikey.com/products/en?keywords=296-1629-5-ND) |
| U4 | Socket | 14-pin | | [37197](https://www.jameco.com/shop/ProductDisplay?productId=37197) | [ED90049-ND](https://www.digikey.com/products/en?keywords=ED90049-ND) |
| U5 | IC | 74LS32 | | [47466](https://www.jameco.com/shop/ProductDisplay?productId=47466) | [296-1658-5-ND](https://www.digikey.com/products/en?keywords=296-1658-5-ND) |
| U5 | Socket | 14-pin | | [37197](https://www.jameco.com/shop/ProductDisplay?productId=37197) | [ED90049-ND](https://www.digikey.com/products/en?keywords=ED90049-ND) |
| U6 | IC | 74LS08 | | [46375](https://www.jameco.com/shop/ProductDisplay?productId=46375) | [296-1633-5-ND](https://www.digikey.com/products/en?keywords=296-1633-5-ND) |
| U6 | Socket | 14-pin | | [37197](https://www.jameco.com/shop/ProductDisplay?productId=37197) | [ED90049-ND](https://www.digikey.com/products/en?keywords=ED90049-ND) |

## Building PCB

So, let's assume you got the PCBs and all the components, listed in the Bill of Materials. First thing is to solder the components on. At this stage you have to decide if you want to try soldering on the SMD components - there are two, each of them being totally optional. FT230X chip is required if you want to have onboard serial USB->UART converter. MicroUSB connector if you want to use this connector standard. You can replace MicroUSB with standard USB B port (and you can also solder both, as I did, but only use one at a time).

Other optional components are:

- UART Port (J2) - it was placed on the board if you decide to skip the FT230X chip, but you still want to use serial connection. You can use this port to connect to one of external USB->UART converters. **Please note:** if your USB->UART converter doesn't expose CTS/RTS lines, you have to connect CTS and RTS lines permanently to ground,
- USB-B Port (J4) - if you prefer to use Micro-USB port,
- Power-In Port (J5) - you can power the computer using any of the USB ports, so this one is optional,
- PS/2 Connector (J6) - you can skip this one, if you don't intend to connect keyboard. Please note - ATtiny must be connected and programmed even if you don't plan to use keyboard - otherwise the lines would be left floating and could cause strange behavior. You can try grounding them using ATtiny socket, but this has not been tested,
- AVR-ISP Port (J9) - required only if you plan to program the ATtiny onboard, otherwise you can program the chip externally, but it requires chip removal each time,
- Expansion Port (J7) - this one can be skipped, if you don't plan to use Arduino Mega bus analyzer nor any extensions, but it's not recommended.

For the soldering, I would suggest to start with the most difficult components - you will probably get more than one board, so use the first one to brave the SMD components. Important step after soldering is to verify if there are any bridges/shorts between adjacent chip/port pins. Since checking the pins itself might be difficult (they are pretty small), it's easier to check on the connected THT pads, and these are:

| FT230X Pin | Connected THT pad on PCB |
| --- | --- |
| 1 | RxD pad of UART Port (J2) |
| 2 | CTS pad of UART Port (J2) |
| 3 | Bottom pads of resistor R10, R11 |
| 4 | TxD pad of UART Port (J2) |
| 5 | Left pad of capacitor C8 |
| 6 | RTS pad of UART Port (J2) |
| 7 | Disconnected |
| 8 | Left pad of resistor R5 |
| 9 | Left pad of resistor R4 |
| 10 | Bottom pads of resistors R10,R11 |
| 11 | Pad 4 of the ACIA chip (U5) |
| 12 | Right pad of capacitor C8 |
| 13 | Left pad of capacitor C8 |
| 14 | Left pad of LED D3 |
| 15 | Left pad of LED D2 |
| 16 | Disconnected |

| MicroUSB Pin | Connected THT pad on PCB |
| --- | --- |
| 1 | Top pad of ferrite bead FB1 |
| 2 | Right pad of capacitor C10 |
| 3 | Right pad of capacitor C9 |
| 4 | Disconnected |
| 5 | Left pad of capacitors C9, C10 |

So, to verify that there is no bridge between pins 5 and 6 of FT230X, connect your multimeter in circuit continuity mode between left pad of capacitor C8 and RTS pad of UART Port (J2). If it beeps, you have bridge between these two pins and you need to check your soldering again.

Repeat for each pair of adjacent pins. You want to have zero beeps :) Please note: this only means that there are no bridges, it doesn't guarantee that your chip is soldered correctly, that will be verified later.

After SMD components are in place (or if you skipped them), solder on all the THT components, starting from the smallest ones and going up the size. There is plenty of redundant space on the board, so this should be pretty easy. Make sure to observe polarity of capacitors and LEDs and be careful when mounting ACIA chip - it's actually oriented differently than the rest of horizontal chips on the board.

After all the components are soldered in place, put the chips in sockets (I recommend using two tooled sockets for ROM - one will be soldered to the board, the other one will be used for easy ROM replacement for programming) and check everything once again - orientation of the chips, visible solder bridges, etc. If it looks good, connect power and you expect the power LED to light up. If this works, go to next step, would be building, installing and running sample programs. This is all covered in [Software documentation](../Software/README.md)

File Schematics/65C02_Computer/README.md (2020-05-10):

Schematics, PCB and Gerbers updates to v002

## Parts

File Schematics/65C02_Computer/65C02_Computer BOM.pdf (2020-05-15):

17 0.1uF | Unpolarized capacitor | https://www.digikey.com/products/en?keywords=399-4151-ND | C1-C5, C7, C12-C18, C20-C23, | Digikey 1 10uF | Polarized capacitor | https://www.digikey.com/products/en?keywords=1189-2322-ND | C6, | Digikey 1 10nF | Unpolarized capacitor | https://www.digikey.com/products/en?keywords=399-4150-ND | C8, | Digikey 2 47pF | Unpolarized capacitor | https://www.digikey.com/products/en?keywords=399-9737-ND | C9, C10, | Digikey 1 1000uF | Polarized capacitor | https://www.digikey.com/products/en?keywords=1189-1745-ND | C11, | Digikey 1 1uf | Unpolarized capacitor | https://www.digikey.com/product-detail/en/kemet/C320C105K5N5TA91707301/399-14394-1-ND/6919016 C19, | Digikey 1 5mm LED Green | Light emitting diode | https://www.digikey.com/products/en?keywords=754-1263-ND | D1, D3 | Digikey 1 | 5mm LED Red | Light emitting diode | https://www.digikey.com/products/en?keywords=754-1264-ND | D2, D4 | Digikey 1 | Ferite bead | Ferrite bead | https://www.digikey.com/products/en?keywords=490-10997-ND | FB1, | Digikey 1 | 1x6 right angle header | FTDI UART Connector | https://www.digikey.com/product-detail/en/w%C3%BCrth-elektronik/61300611021/732-5339-ND/4846832 J1, | Digikey 1 | USB Mini Jack | USB Mini Type B connector | https://www.digikey.com/product-detail/en/te-connectivity-amp-connectors/1734510-1/A107788-ND/4021669 J2, | Digikey 1 | DC Barrel Jack | Power Connector | https://www.digikey.com/product-detail/en/cui-devices/PJ-102AH/CP-102AH-ND/408448 | J3, | Digikey 1 | Mini-DIN-6 | Mini-DIN-6 Keyboard Connector | https://www.digikey.com/products/en?keywords=CP-2260-ND | J4, | Digikey 1 | SJ1-3523N Audio Jack | Audio Jack, 3 Poles (Stereo / TRS) | https://www.digikey.com/product-detail/en/cui-devices/SJ1-3523N/CP1-3523N-ND/738689 | J5, | Digikey 1 | 6 pin AVR ISP | Atmel 6-pin ISP connector | https://www.digikey.com/products/en?keywords=609-3234-ND | J6, | Digikey 1 | 2x16 female header | Expansion Port | https://www.digikey.com/product-detail/en/sullins-connector-solutions/PPPC162LFBN-RC/S7119-ND/810255 J7, | Digikey 6 | 1x12 female header | VIA Ports | https://www.digikey.com/product-detail/en/sullins-connector-solutions/PPPC121LFBN-RC/S7045-ND/810184 J8-J13 | Digikey 2 | 1x16 female header | LCD Connector | https://www.digikey.com/product-detail/en/sullins-connector-solutions/PPPC161LFBN-RC/S7049-ND/810188 J14-J15 | Digikey 10 | 2x 12 male pinr header | cut for 2 pin male headers | https://www.digikey.com/product-detail/en/amphenol-icc-fci/67997-112HLF/609-3227-ND/1878550 J16-18 22-25 27-28 30-31 33-37 39-51 60-78 82-91 | Digikey 1 | 1 pin male header | cut for 1 pin male headers | https://www.digikey.com/product-detail/en/amphenol-icc-fci/68001-212HLF/609-3280-ND/1878537 J26, J29, J32, J79, J80, J81, | Digikey 1 | 3x7 male header | Combined for 7, 1x3 LCD jumpers | https://www.digikey.com/product-detail/en/samtec-inc/TSW-107-07-L-T/TSW-107-07-L-T-ND/7867706J53, J54, J55, J56, J57, J58, J59, | Digikey 1 | 1M ohm | Resistor | https://www.digikey.com/product-detail/en/stackpole-electronics-inc/CF14JT1M00/CF14JT1M00CT-ND/1830423 R1, | Digikey 1 | 47k ohm | Resistor | https://www.digikey.com/product-detail/en/stackpole-electronics-inc/RC14JT47K0/RC14JT47K0CT-ND/10127355 R2, | Digikey 1 | 10k ohm | Resistor | https://www.digikey.com/product-detail/en/stackpole-electronics-inc/CF14JT10K0/CF14JT10K0CT-ND/1830374 R3, | Digikey 2 | 27 ohm | Resistor | https://www.digikey.com/product-detail/en/stackpole-electronics-inc/CF14JT27R0/CF14JT27R0CT-ND/1830313 R4, R5, | Digikey 6 | 3.3k ohm | Resistor | https://www.digikey.com/product-detail/en/stackpole-electronics-inc/CF14JT3K30/CF14JT3K30CT-ND/1830362 R6, R7, R8, R14, R15, R17, | Digikey 4 | 270 ohm | Resistor | https://www.digikey.com/product-detail/en/stackpole-electronics-inc/CF14JT270R/CF14JT270RCT-ND/1830336 R9, R10, R11, R12, | Digikey 1 | 1k ohm | Resistor | https://www.digikey.com/product-detail/en/stackpole-electronics-inc/CF14JT1K00/CF14JT1K00CT-ND/1830350 R16, | Digikey 1 | 10k trimpot Piher_PT-6-V | Potentiometer | https://www.digikey.com/product-detail/en/amphenol-piher-sensing-systems/PT6MV-103A2020/1993-1052-ND/9555890 RV1, | Digikey 1 | Standard pushbutton 6mm | Push button switch | https://www.digikey.com/product-detail/en/te-connectivity-alcoswitch-switches/1825910-6/450-1650-ND/1632536 SW1, | Digikey 1 | 74HC21 | Dual 4-input AND | https://www.digikey.com/products/en?keywords=296-8266-5-ND | U1, | Digikey 1 | 74HC00 | quad 2-input NAND gate | https://www.digikey.com/products/en?keywords=296-1563-5-ND | U2, | Digikey 1 | 74HC02 | quad 2-input NOR gate | https://www.digikey.com/products/en?keywords=296-1564-5-ND | U3, | Digikey 1 | NE555 | Precision Timers, DIP-8/SOIC-8 | https://www.digikey.com/products/en?keywords=296-NE555P-ND | U4, | Digikey 1 | R6551 | See Note Below: | https://www.jameco.com/shop/ProductDisplay?catalogId=10001&langId=-1&storeId=10001&productId=43318 U5, | Jameco
1 | 65C51N | See Note Below: (Out of stock?) | http://www.westerndesigncenter.com/wdc/w65c51n-chip.cfm | U5, | WDC
1 | FT230XS | USB SERIAL BASIC UART | https://www.digikey.com/products/en?keywords=768-1135-1-ND | U6, | Digikey 1 | 65C02S | MPU 8-Bit 14MHz | https://www.jameco.com/shop/ProductDisplay?productId=2143638 | U7, | Jameco
1 | 28C256 EEPROM | EEPROM 256K (Get Extra to swap EEPROM) | https://www.digikey.com/products/en?keywords=AT28C256-15PU-ND | U8, | Digikey 1 | 62256 RAM | SRAM 256K | https://www.digikey.com/products/en?keywords=1450-1480-ND | U9, | Digikey 1 | ATtiny4313-PU | MCU 8BIT 4KB | https://www.digikey.com/products/en?keywords=ATTINY4313-PU-ND | U10, | Digikey 3 | 65C22S VIA | Versatile Interface Adapter | https://www.jameco.com/shop/ProductDisplay?productId=2143591 | U11, U12, U13, | Jameco
1 | SN76489AN | Audi Chip | https://www.twistywristarcade.com/search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 U14, | Twist Wrist Arcade
1 | 1 MHz | XTAL OSC XO 1.0000MHZ | https://www.digikey.com/products/en?keywords=ECS-100AX-010 | X1, | Digikey 1 | 1.8432 MHz | XTAL OSC XO 1.8432MHZ | https://www.digikey.com/products/en?keywords=ECS-100AX-018 | X2, | Digikey 1 | 4 MHz | TAL OSC XO 4.0000MHZ | https://www.digikey.com/products/en?keywords=ECS-100AX-040 | X3, | Digikey 3 | DIP 14 x7mm socket | https://www.digikey.com/products/en?keywords=110-44-314-41-001000 | U1-U3 | Digikey 1 | DIP 8 x7mm socket | https://www.digikey.com/products/en?keywords=110-44-308-41-001000 | U4, | Digikey 1 | DIP 16 x7mm socket | https://www.digikey.com/products/en?keywords=110-44-316-41-001000 | U14, | Digikey 1 | DIP 20 x7mm socket | https://www.digikey.com/products/en?keywords=110-44-320-41-001000 | U10, | Digikey 2 | DIP 28 x7mm socket | Get extra to swap EEPROM | https://www.digikey.com/products/en?keywords=110-44-628-41-001000 | U8-U9 | Digikey 4 | DIP 40 x15mm socket | https://www.digikey.com/products/en?keywords=110-44-640-41-001000 | U7, U11-U13 | Digikey 3 | DIP 14 x7mm Oscillator sockets | https://www.digikey.com/product-detail/en/aries-electronics/1107741/A462-ND/261894 | X1, X2, X3 | Digikey 50 | 2 pin jumpers | https://www.digikey.com/product-detail/en/sullins-connector-solutions/SPC02SYAN/S9001-ND/76375Jumpers | Digikey

Notes: Some references were deleted from the schematic and not added back

[ Important note about the ACIA chip: There are basically two types of chips that can be used. Modern, rated to higher frequencies WDC65C51 and older, Rockwell 6551P chips, rated only for 1MHz. The problem with former is that there is a bug with interrupt handling on transmit operation - both IRQ and status flag polling fail, you have to implement dead loop to wait long enough for the byte to be transmitted. Latter chip is probably no longer manufactured, but can be purchased online from Chinese sellers - these are cheap, but not all of them work correctly, so get more than one to be safe. For me the second chip worked correctly and both polling and IRQ-based transmit work as expected.

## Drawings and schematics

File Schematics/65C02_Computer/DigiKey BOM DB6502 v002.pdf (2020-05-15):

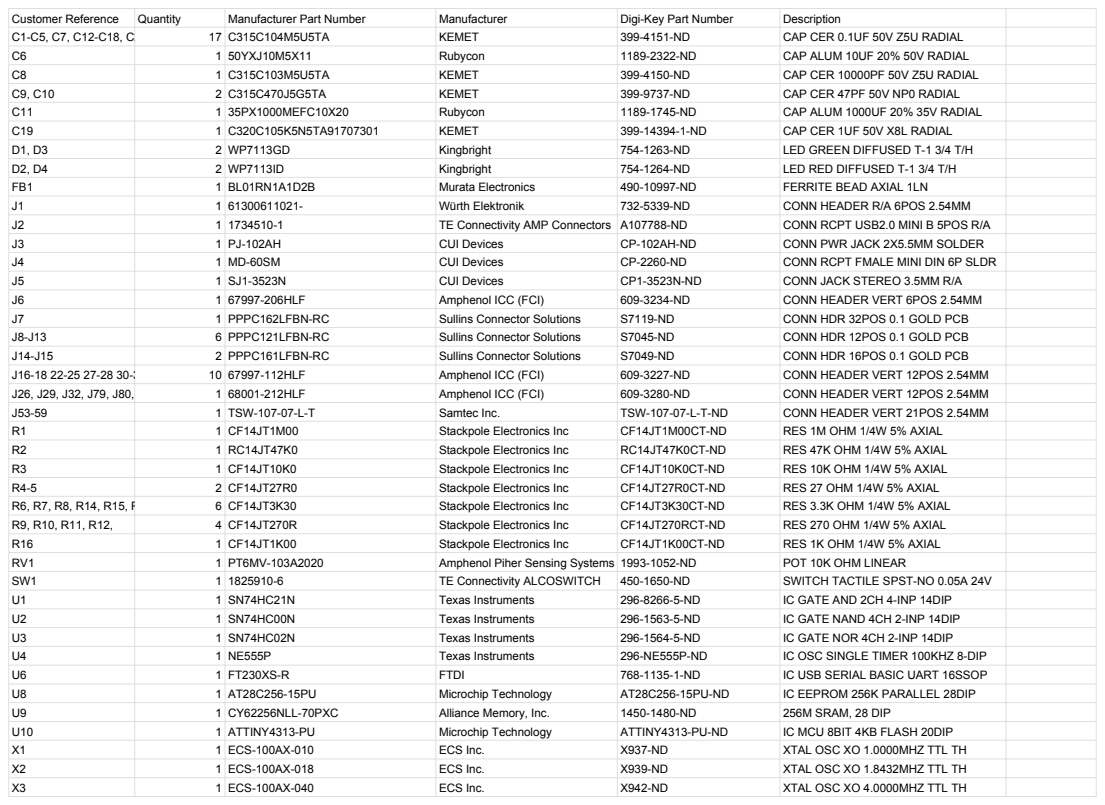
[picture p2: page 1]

U1-3 | 3 | 110-44-314-41-001000 | Mill-Max Manufacturing Corp. | ED90049-ND | CONN IC DIP SOCKET 14POS TIN
U4 | 1 | 110-44-308-41-001000 | Mill-Max Manufacturing Corp. | ED90048-ND | CONN IC DIP SOCKET 8POS TIN
U5,U8-9 | 3 | 110-44-628-41-001000 | Mill-Max Manufacturing Corp. | ED90057-ND | CONN IC DIP SOCKET 28POS TIN
U7, U11-13 | 4 | 110-44-640-41-001000 | Mill-Max Manufacturing Corp. | ED90059-ND | CONN IC DIP SOCKET 40POS TIN
U10 | 1 | 110-44-320-41-001000 | Mill-Max Manufacturing Corp. | ED90052-ND | CONN IC DIP SOCKET 20POS TIN
U14 | 1 | 110-44-316-41-001000 | Mill-Max Manufacturing Corp. | ED90050-ND | CONN IC DIP SOCKET 16POS TIN
X1-3 | 3 | 1107741- | Aries Electronics | A462-ND | OSCILLATOR SOCKET FULL SIZE 4PIN
Jumpers | 50 | SPC02SYAN | Sullins Connector Solutions | S9001-ND | CONN JUMPER SHORTING GOLD FLASH

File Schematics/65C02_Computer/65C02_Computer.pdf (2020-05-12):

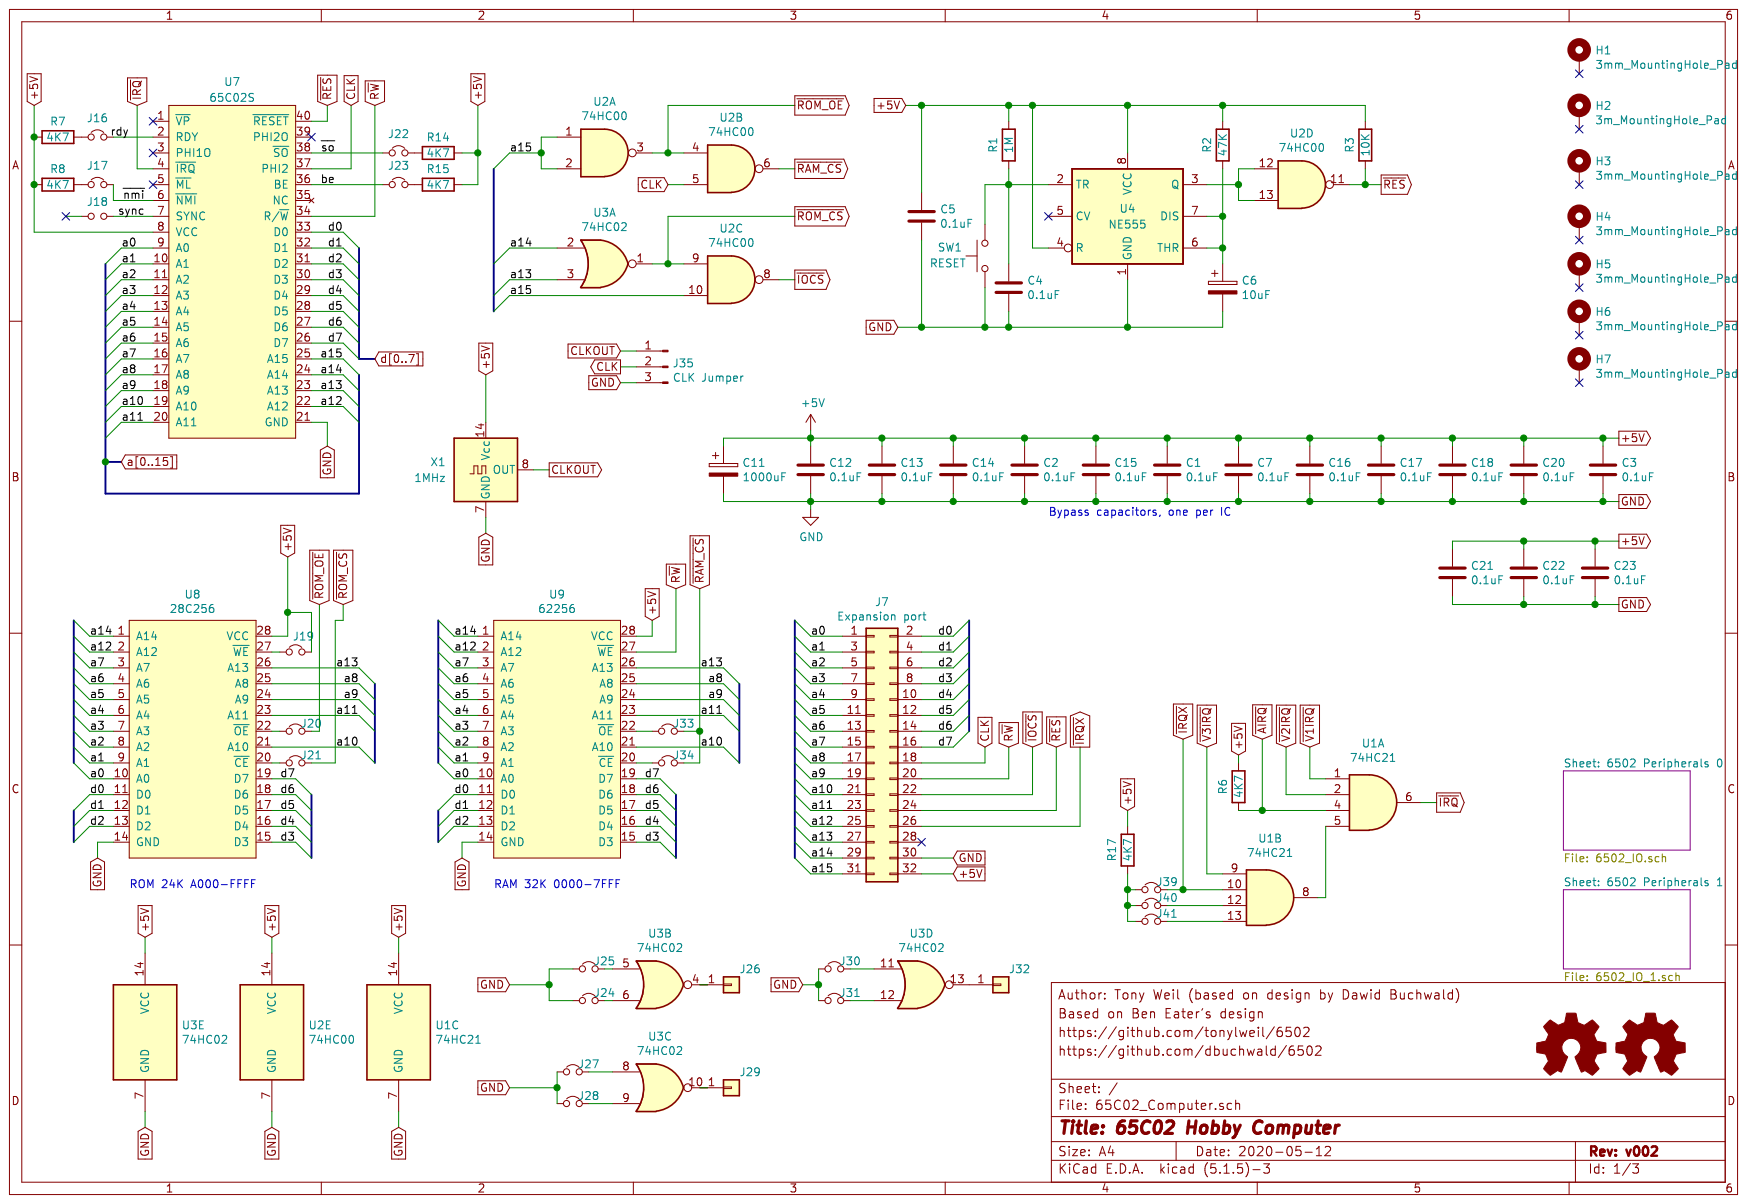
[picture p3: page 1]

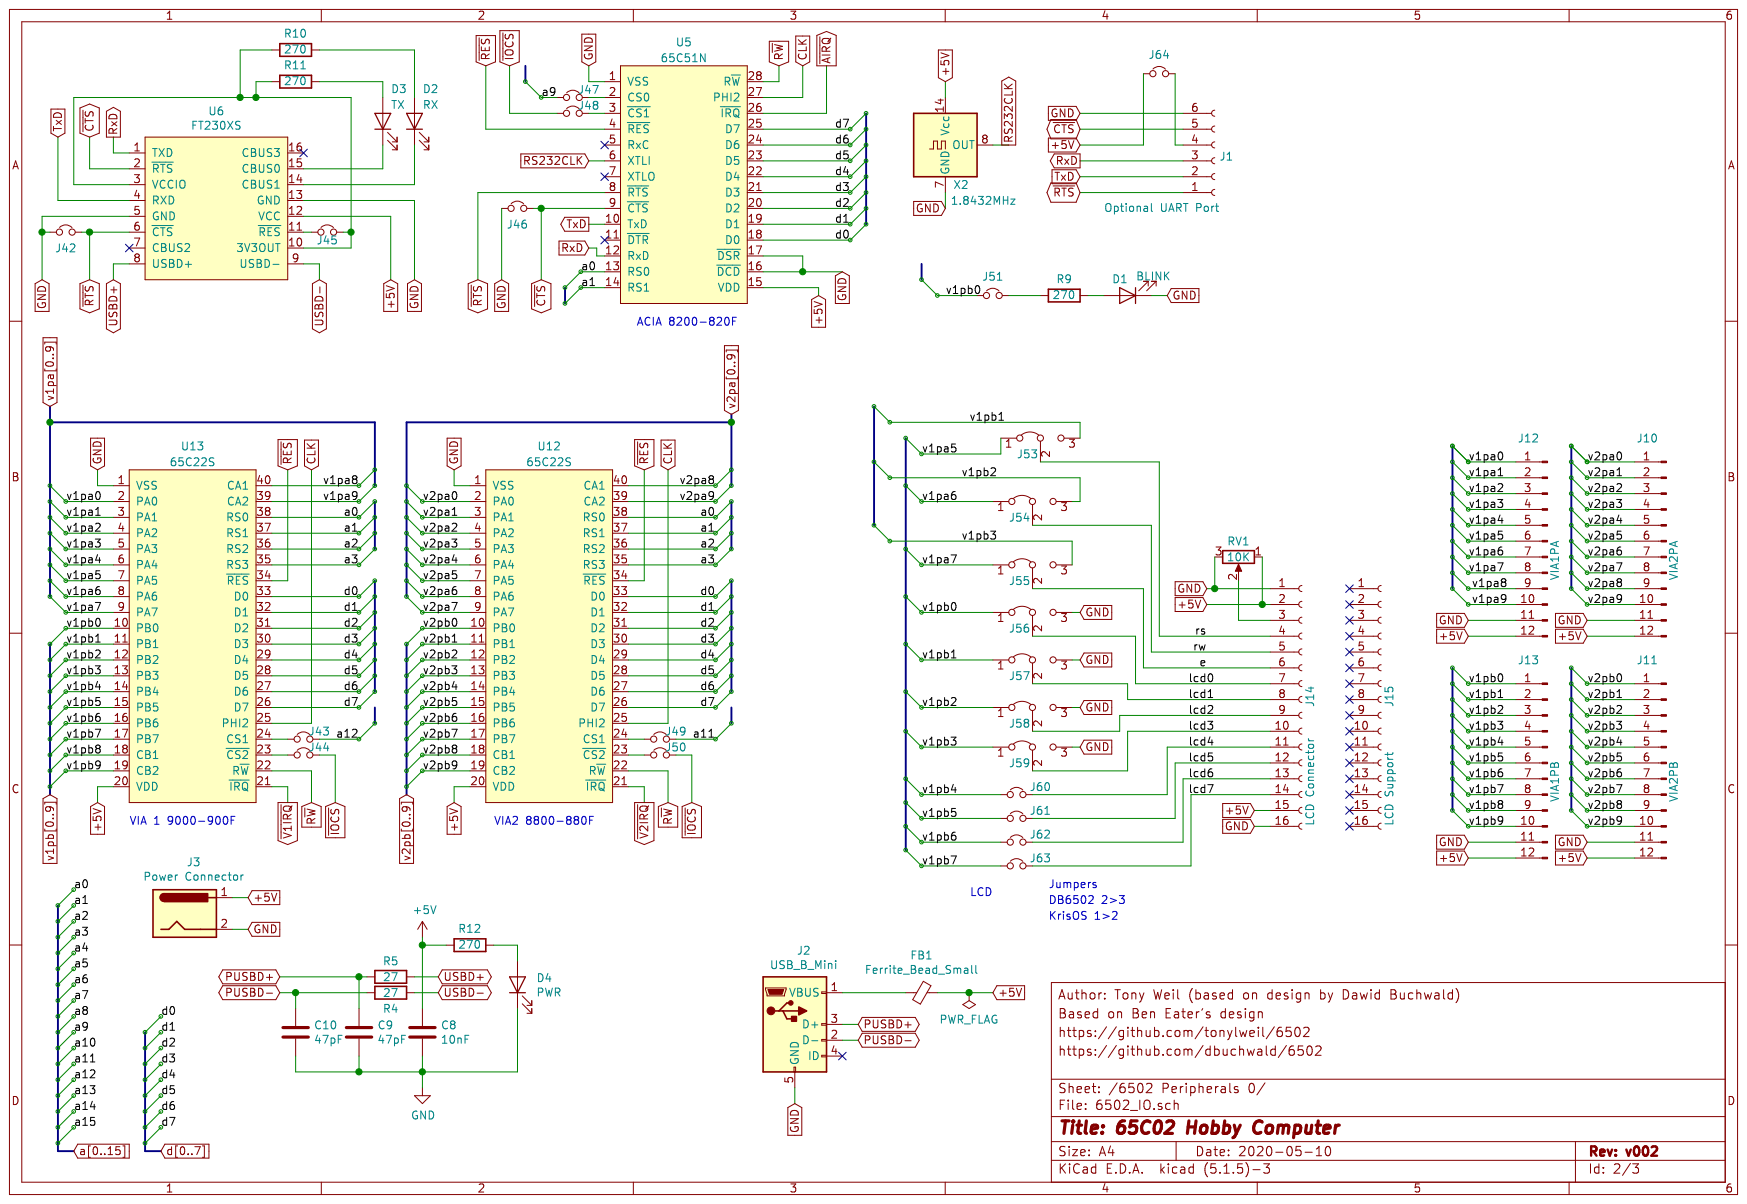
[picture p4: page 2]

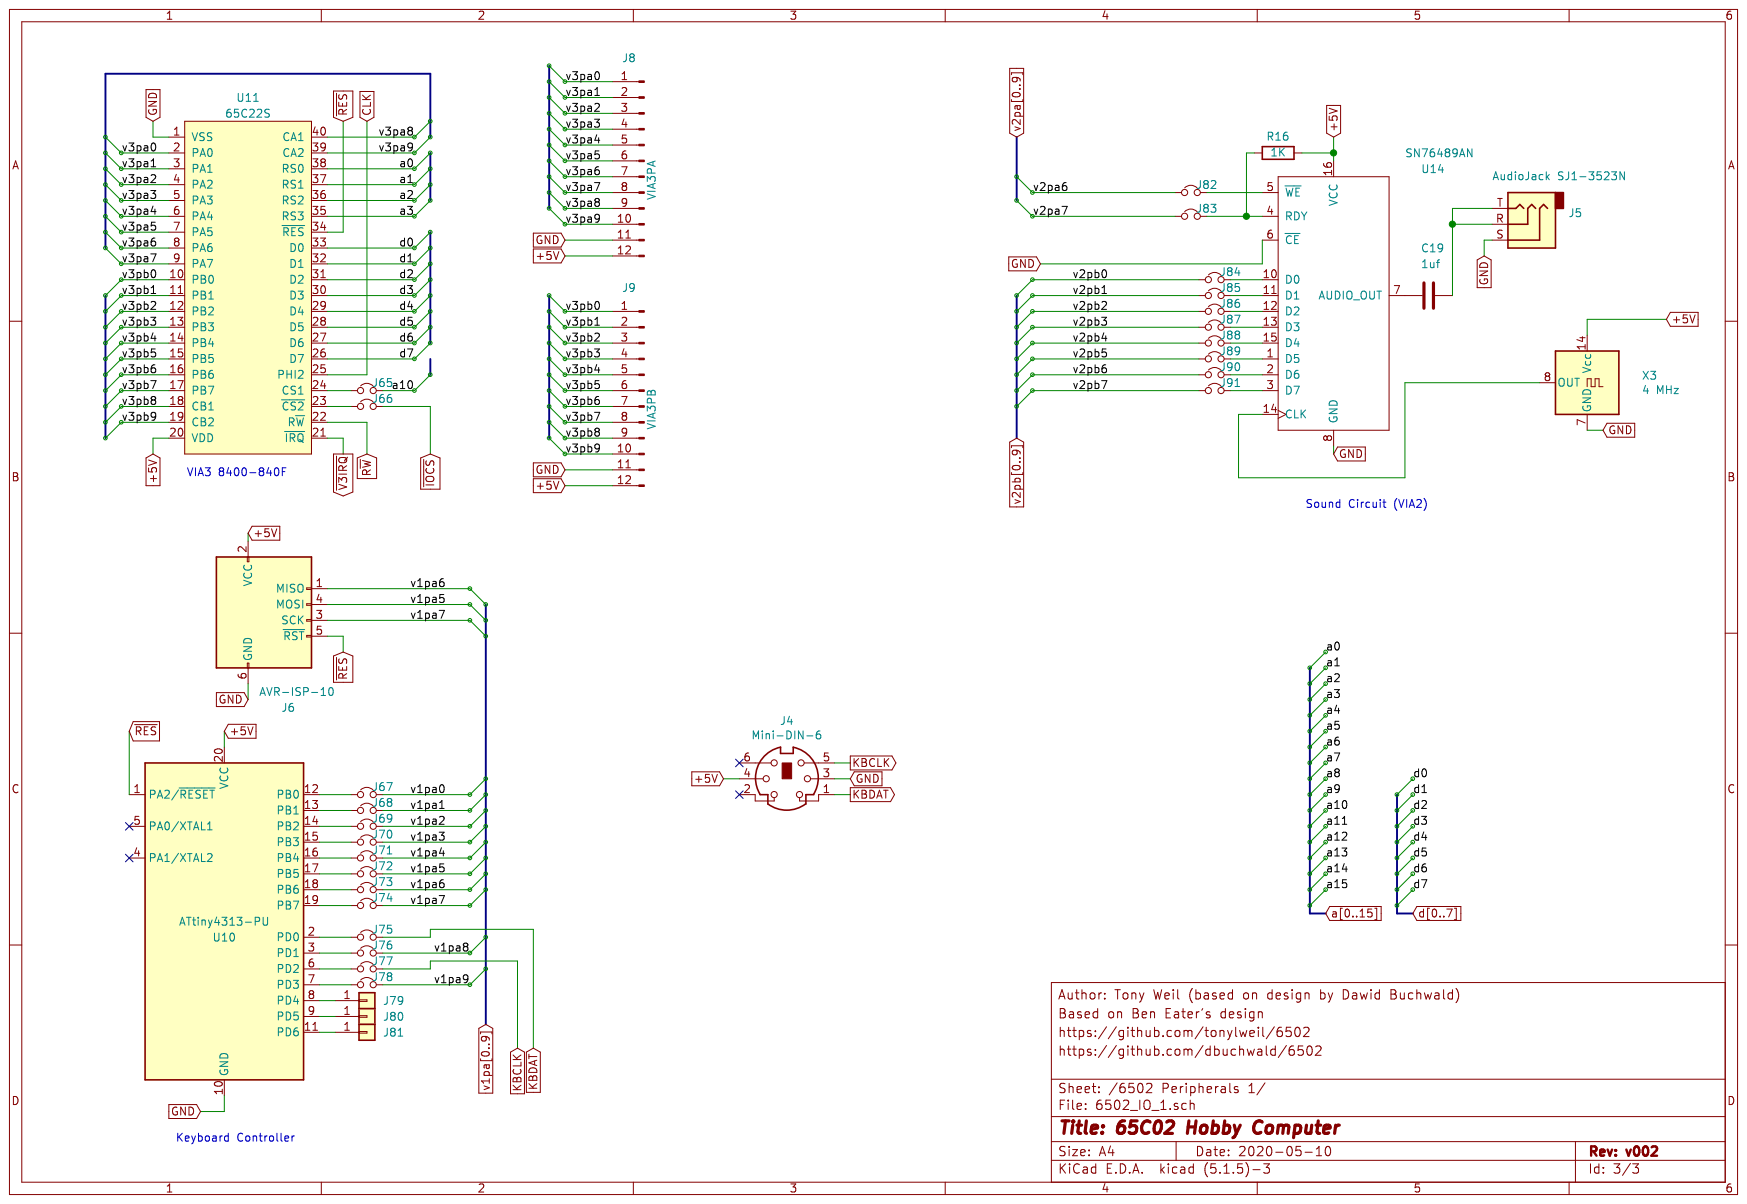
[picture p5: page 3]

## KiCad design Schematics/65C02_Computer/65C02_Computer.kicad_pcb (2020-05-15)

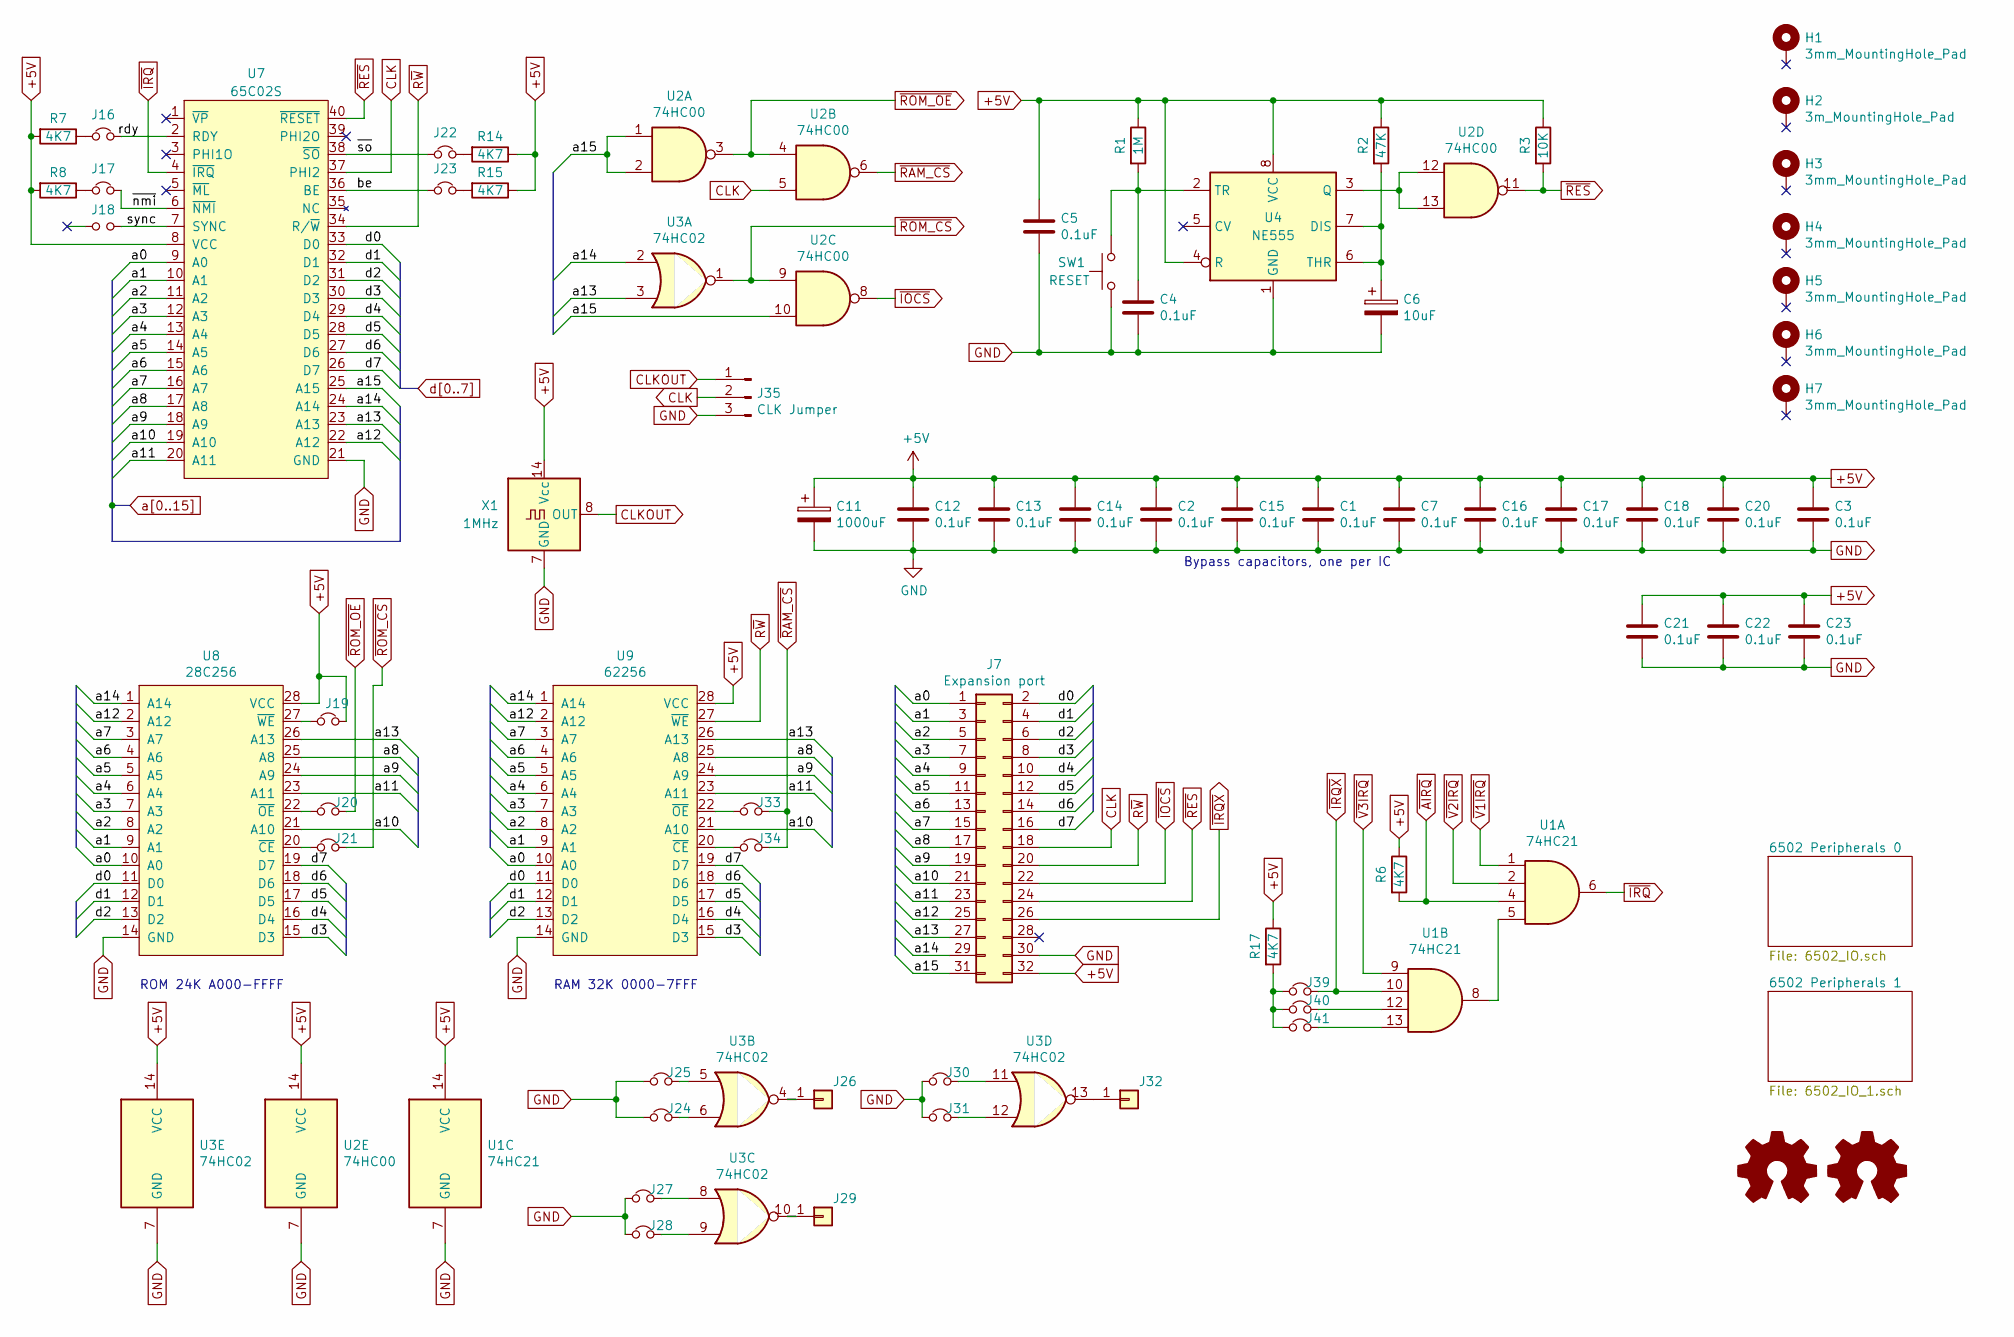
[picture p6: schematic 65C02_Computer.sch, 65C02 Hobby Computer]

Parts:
C1, C2, C3, C4, C5, C7, C12, C13, C14, C15, C16, C17, C18, C20, C21, C22, C23: 0.1uF; C_Disc_D3.4mm_W2.1mm_P2.50mm
C6: 10uF; CP_Radial_D5.0mm_P2.50mm
C11: 1000uF; CP_Radial_D10.0mm_P5.00mm
H1, H3, H4, H5, H6, H7: 3mm_MountingHole_Pad; MountingHole_3.2mm_Pad
H2: 3m_MountingHole_Pad; MountingHole_3.2mm_Pad
J7: Expansion port; PinSocket_2x16_P2.54mm_Vertical
J16, J17, J18, J22, J23, J39, J40, J41: J; PinHeader_1x02_P2.54mm_Vertical_Close
J19, J20, J21, J24, J25, J27, J28, J30, J31, J33, J34: Jumper_NC_Small; PinHeader_1x02_P2.54mm_Vertical_Close
J26, J29, J32: Conn_01x01; PinHeader_1x01_P2.54mm_Vertical_Close
J35: CLK Jumper; PinHeader_1x03_P2.54mm_Vertical_Close
LOGO1: Logo_Open_Hardware_Small; KiCad-Logo2_5mm_SilkScreen
LOGO2: Logo_Open_Hardware_Small; OSHW-Logo_5.7x6mm_SilkScreen
R1: 1M; R_Axial_DIN0207_L6.3mm_D2.5mm_P7.62mm_Horizontal
R2: 47K; R_Axial_DIN0207_L6.3mm_D2.5mm_P7.62mm_Horizontal
R3: 10K; R_Axial_DIN0207_L6.3mm_D2.5mm_P7.62mm_Horizontal
R6, R7, R8, R14, R15, R17: 4K7; R_Axial_DIN0207_L6.3mm_D2.5mm_P7.62mm_Horizontal
SW1: RESET; SW_PUSH_6mm_H4.3mm
U1: 74HC21; DIP-14_W7.62mm_Socket
U2: 74HC00; DIP-14_W7.62mm_Socket
U3: 74HC02; DIP-14_W7.62mm_Socket
U4: NE555; DIP-8_W7.62mm_Socket
U7: 65C02S; DIP-40_W15.24mm_Socket
U8: 28C256; DIP-28_W15.24mm_Socket
U9: 62256; DIP-28_W15.24mm_Socket
X1: 1MHz; Oscillator_DIP-14

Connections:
+5V: C1.1, C2.1, C3.1, C5.1, C7.1, C11.1, C12.1, C13.1, C14.1, C15.1, C16.1, C17.1, C18.1, C20.1, C21.1, C22.1, C23.1, J7.32, J19.2, R1.1, R2.1, R3.1, R6.1, R7.2, R8.2, R14.1, R15.1, R17.1, U1.14 (VCC), U2.14 (VCC), U3.14 (VCC), U4.4 (R), U4.8 (VCC), U7.8 (VCC), U8.28 (VCC), U9.28 (VCC), X1.14 (Vcc); also elsewhere on the board
/be: J23.1, U7.36 (BE)
/rdy: J16.2, U7.2 (RDY)
/sync: J18.2, U7.7 (SYNC)
/~nmi: J17.2, U7.6 (~NMI)
/~so: J22.1, U7.38 (~SO)
CLK: J7.18, J35.2, U2.5, U7.37 (PHI2); also elsewhere on the board
CLKOUT: J35.1, X1.8 (OUT)
GND: C1.2, C2.2, C3.2, C4.2, C5.2, C6.2, C7.2, C11.2, C12.2, C13.2, C14.2, C15.2, C16.2, C17.2, C18.2, C20.2, C21.2, C22.2, C23.2, J7.30, J24.1, J25.1, J27.1, J28.1, J30.1, J31.1, J35.3, SW1.1, U1.7 (GND), U2.7 (GND), U3.7 (GND), U4.1 (GND), U7.21 (GND), U8.14 (GND), U9.14 (GND), X1.7 (GND); also elsewhere on the board
unnamed: C4.1, R1.2, SW1.2, U4.2 (TR)
unnamed: C6.1, R2.2, U4.6 (THR), U4.7 (DIS)
unnamed: J16.1, R7.1
unnamed: J17.1, R8.1
unnamed: J19.1, U8.27 (~WE)
unnamed: J20.1, U8.22 (~OE)
unnamed: J21.1, U8.20 (~CE)
unnamed: J22.2, R14.2
unnamed: J23.2, R15.2
unnamed: J24.2, U3.6
unnamed: J25.2, U3.5
unnamed: J26.1, U3.4
unnamed: J27.2, U3.8
unnamed: J28.2, U3.9
unnamed: J29.1, U3.10
unnamed: J30.2, U3.11
unnamed: J31.2, U3.12
unnamed: J32.1, U3.13
unnamed: J33.1, U9.22 (~OE)
unnamed: J34.1, U9.20 (~CE)
unnamed: J39.1, J40.1, J41.1, R17.2
unnamed: J40.2, U1.12
unnamed: J41.2, U1.13
unnamed: U1.5, U1.8
unnamed: U2.12, U2.13, U4.3 (Q)
R~W: J7.20, U7.34 (R/~W), U9.27 (~WE); also elsewhere on the board
a0: J7.1, U7.9 (A0), U8.10 (A0), U9.10 (A0); also elsewhere on the board
a1: J7.3, U7.10 (A1), U8.9 (A1), U9.9 (A1); also elsewhere on the board
a2: J7.5, U7.11 (A2), U8.8 (A2), U9.8 (A2); also elsewhere on the board
a3: J7.7, U7.12 (A3), U8.7 (A3), U9.7 (A3); also elsewhere on the board
a4: J7.9, U7.13 (A4), U8.6 (A4), U9.6 (A4)
a5: J7.11, U7.14 (A5), U8.5 (A5), U9.5 (A5)
a6: J7.13, U7.15 (A6), U8.4 (A6), U9.4 (A6)
a7: J7.15, U7.16 (A7), U8.3 (A7), U9.3 (A7)
a8: J7.17, U7.17 (A8), U8.25 (A8), U9.25 (A8)
a9: J7.19, U7.18 (A9), U8.24 (A9), U9.24 (A9); also elsewhere on the board
a10: J7.21, U7.19 (A10), U8.21 (A10), U9.21 (A10); also elsewhere on the board
a11: J7.23, U7.20 (A11), U8.23 (A11), U9.23 (A11); also elsewhere on the board
a12: J7.25, U7.22 (A12), U8.2 (A12), U9.2 (A12); also elsewhere on the board
a13: J7.27, U3.3, U7.23 (A13), U8.26 (A13), U9.26 (A13)
a14: J7.29, U3.2, U7.24 (A14), U8.1 (A14), U9.1 (A14)
a15: J7.31, U2.1, U2.2, U2.10, U7.25 (A15)
d0: J7.2, U7.33 (D0), U8.11 (D0), U9.11 (D0); also elsewhere on the board
d1: J7.4, U7.32 (D1), U8.12 (D1), U9.12 (D1); also elsewhere on the board
d2: J7.6, U7.31 (D2), U8.13 (D2), U9.13 (D2); also elsewhere on the board
d3: J7.8, U7.30 (D3), U8.15 (D3), U9.15 (D3); also elsewhere on the board
d4: J7.10, U7.29 (D4), U8.16 (D4), U9.16 (D4); also elsewhere on the board
d5: J7.12, U7.28 (D5), U8.17 (D5), U9.17 (D5); also elsewhere on the board
d6: J7.14, U7.27 (D6), U8.18 (D6), U9.18 (D6); also elsewhere on the board
d7: J7.16, U7.26 (D7), U8.19 (D7), U9.19 (D7); also elsewhere on the board
~AIRQ: R6.2, U1.4; also elsewhere on the board
~IOCS: J7.22, U2.8; also elsewhere on the board
~IRQ: U1.6, U7.4 (~IRQ)
~IRQX: J7.26, J39.2, U1.10
~RAM_CS: J33.2, J34.2, U2.6
~RES: J7.24, R3.2, U2.11, U7.40 (~RESET); also elsewhere on the board
~ROM_CS: J21.2, U2.9, U3.1
~ROM_OE: J20.2, U2.3, U2.4
~V1IRQ: U1.1; also elsewhere on the board
~V2IRQ: U1.2; also elsewhere on the board
~V3IRQ: U1.9; also elsewhere on the board

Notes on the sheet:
ROM 24K A000-FFFF
RAM 32K 0000-7FFF
Bypass capacitors, one per IC

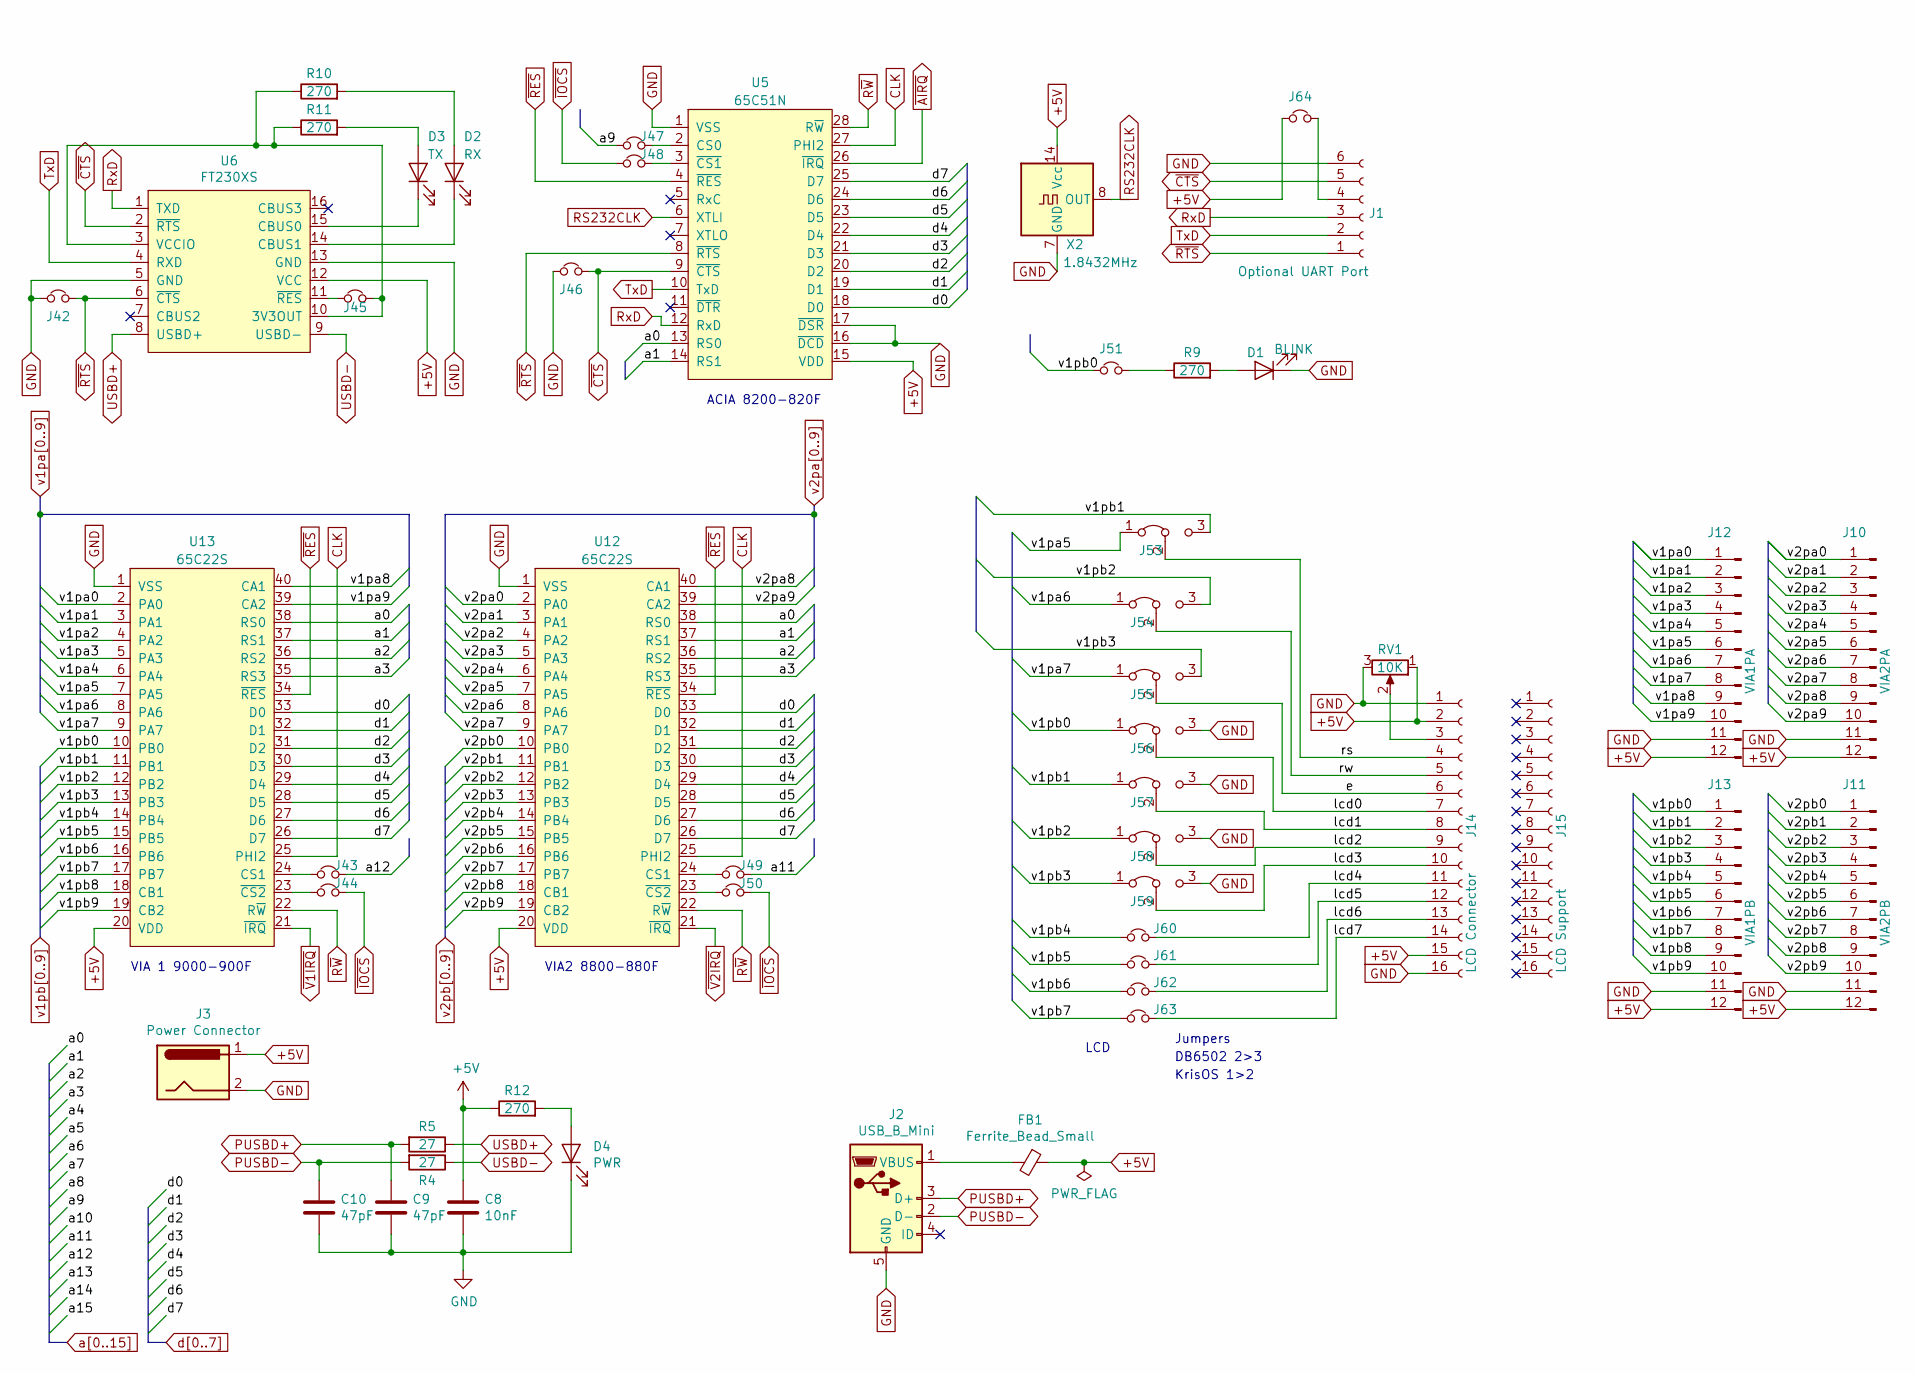
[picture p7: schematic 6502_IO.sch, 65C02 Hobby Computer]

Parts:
C8: 10nF; C_Disc_D3.4mm_W2.1mm_P2.50mm
C9, C10: 47pF; C_Disc_D3.4mm_W2.1mm_P2.50mm
D1: BLINK; LED_D5.0mm_Clear
D2: RX; LED_D5.0mm_Clear
D3: TX; LED_D5.0mm_Clear
D4: PWR; LED_D5.0mm_Clear
FB1: Ferrite_Bead_Small; R_Axial_DIN0207_L6.3mm_D2.5mm_P7.62mm_Horizontal
J1: Optional UART Port; PinSocket_1x06_P2.54mm_Horizontal
J2: USB_B_Mini; USB-MINI-B-PTH-1734510
J3: Power Connector; BarrelJack_Horizontal
J10: VIA2PA; PinSocket_1x12_P2.54mm_Vertical
J11: VIA2PB; PinSocket_1x12_P2.54mm_Vertical
J12: VIA1PA; PinSocket_1x12_P2.54mm_Vertical
J13: VIA1PB; PinSocket_1x12_P2.54mm_Vertical
J14: LCD Connector; LCD-4line
J15: LCD Support; PinSocket_1x16_P2.54mm_Vertical
J42, J43, J44, J45, J47, J48, J49, J50, J51, J60, J61, J62, J63, J64: Jumper_NC_Small; PinHeader_1x02_P2.54mm_Vertical_Close
J46: Jumper_NC_Small; PinHeader_1x02_P2.54mm_Vertical
J53, J54, J55, J56, J57, J58, J59: Jumper_3_Bridged12; PinHeader_1x03_P2.54mm_Vertical_Close
R4, R5: 27; R_Axial_DIN0207_L6.3mm_D2.5mm_P7.62mm_Horizontal
R9, R10, R11, R12: 270; R_Axial_DIN0207_L6.3mm_D2.5mm_P7.62mm_Horizontal
RV1: 10K; Potentiometer_Piher_PT-6-V_Vertical
U5: 65C51N; DIP-28_W15.24mm_Socket
U6: FT230XS; SSOP-16_3.9x4.9mm_P0.635mm_long_pads
U12, U13: 65C22S; DIP-40_W15.24mm_Socket
X2: 1.8432MHz; Oscillator_DIP-14

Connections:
+5V: C8.1, FB1.1, J3.1, J10.12, J11.12, J12.12, J13.12, J14.2, J14.15, J64.1, R12.1, RV1.1, U5.15 (VDD), U6.12 (VCC), U12.20 (VDD), U13.20 (VDD), X2.14 (Vcc); also elsewhere on the board
/6502 Peripherals 0/e: J14.6, J55.2 (C)
/6502 Peripherals 0/lcd0: J14.7, J56.2 (C)
/6502 Peripherals 0/lcd1: J14.8, J57.2 (C)
/6502 Peripherals 0/lcd2: J14.9, J58.2 (C)
/6502 Peripherals 0/lcd3: J14.10, J59.2 (C)
/6502 Peripherals 0/lcd4: J14.11, J60.2
/6502 Peripherals 0/lcd5: J14.12, J61.2
/6502 Peripherals 0/lcd6: J14.13, J62.2
/6502 Peripherals 0/lcd7: J14.14, J63.2
/6502 Peripherals 0/rs: J14.4, J53.2 (C)
/6502 Peripherals 0/rw: J14.5, J54.2 (C)
CLK: U5.27 (PHI2), U12.25 (PHI2), U13.25 (PHI2); also elsewhere on the board
GND: C8.2, C9.2, C10.2, D1.1 (K), D4.1 (K), J1.6, J2.5 (GND), J3.2, J10.11, J11.11, J12.11, J13.11, J14.1, J14.16, J42.1, J46.1, J56.3 (B), J57.3 (B), J58.3 (B), J59.3 (B), RV1.3, U5.1 (VSS), U5.16 (~DCD), U5.17 (~DSR), U6.5 (GND), U6.13 (GND), U12.1 (VSS), U13.1 (VSS), X2.7 (GND); also elsewhere on the board
unnamed: D1.2 (A), R9.2
unnamed: D2.1 (K), U6.14 (CBUS1)
unnamed: D2.2 (A), R10.2
unnamed: D3.1 (K), U6.15 (CBUS0)
unnamed: D3.2 (A), R11.2
unnamed: D4.2 (A), R12.2
unnamed: FB1.2, J2.1 (VBUS)
unnamed: J1.4, J64.2
unnamed: J14.3, RV1.2
unnamed: J43.1, U13.24 (CS1)
unnamed: J44.1, U13.23 (~CS2)
unnamed: J45.1, U6.11 (~RES)
unnamed: J45.2, R10.1, R11.1, U6.3 (VCCIO), U6.10 (3V3OUT)
unnamed: J47.2, U5.2 (CS0)
unnamed: J48.2, U5.3 (~CS1)
unnamed: J49.1, U12.24 (CS1)
unnamed: J50.1, U12.23 (~CS2)
unnamed: J51.2, R9.1
PUSBD+: C9.1, J2.3 (D+), R5.2
PUSBD-: C10.1, J2.2 (D-), R4.2
RS232CLK: U5.6 (XTLI), X2.8 (OUT)
RxD: J1.3, U5.12 (RxD), U6.1 (TXD)
R~W: U5.28 (R~W), U12.22 (R~W), U13.22 (R~W); also elsewhere on the board
TxD: J1.2, U5.10 (TxD), U6.4 (RXD)
USBD+: R5.1, U6.8 (USBD+)
USBD-: R4.1, U6.9 (USBD-)
a0: U5.13 (RS0), U12.38 (RS0), U13.38 (RS0); also elsewhere on the board
a1: U5.14 (RS1), U12.37 (RS1), U13.37 (RS1); also elsewhere on the board
a2: U12.36 (RS2), U13.36 (RS2); also elsewhere on the board
a3: U12.35 (RS3), U13.35 (RS3); also elsewhere on the board
a9: J47.1; also elsewhere on the board
a11: J49.2; also elsewhere on the board
a12: J43.2; also elsewhere on the board
d0: U5.18 (D0), U12.33 (D0), U13.33 (D0); also elsewhere on the board
d1: U5.19 (D1), U12.32 (D1), U13.32 (D1); also elsewhere on the board
d2: U5.20 (D2), U12.31 (D2), U13.31 (D2); also elsewhere on the board
d3: U5.21 (D3), U12.30 (D3), U13.30 (D3); also elsewhere on the board
d4: U5.22 (D4), U12.29 (D4), U13.29 (D4); also elsewhere on the board
d5: U5.23 (D5), U12.28 (D5), U13.28 (D5); also elsewhere on the board
d6: U5.24 (D6), U12.27 (D6), U13.27 (D6); also elsewhere on the board
d7: U5.25 (D7), U12.26 (D7), U13.26 (D7); also elsewhere on the board
v1pa0: J12.1, U13.2 (PA0); also elsewhere on the board
v1pa1: J12.2, U13.3 (PA1); also elsewhere on the board
v1pa2: J12.3, U13.4 (PA2); also elsewhere on the board
v1pa3: J12.4, U13.5 (PA3); also elsewhere on the board
v1pa4: J12.5, U13.6 (PA4); also elsewhere on the board
v1pa5: J12.6, J53.1 (A), U13.7 (PA5); also elsewhere on the board
v1pa6: J12.7, J54.1 (A), U13.8 (PA6); also elsewhere on the board
v1pa7: J12.8, J55.1 (A), U13.9 (PA7); also elsewhere on the board
v1pa8: J12.9, U13.40 (CA1); also elsewhere on the board
v1pa9: J12.10, U13.39 (CA2); also elsewhere on the board
v1pb0: J13.1, J51.1, J56.1 (A), U13.10 (PB0)
v1pb1: J13.2, J53.3 (B), J57.1 (A), U13.11 (PB1)
v1pb2: J13.3, J54.3 (B), J58.1 (A), U13.12 (PB2)
v1pb3: J13.4, J55.3 (B), J59.1 (A), U13.13 (PB3)
v1pb4: J13.5, J60.1, U13.14 (PB4)
v1pb5: J13.6, J61.1, U13.15 (PB5)
v1pb6: J13.7, J62.1, U13.16 (PB6)
v1pb7: J13.8, J63.1, U13.17 (PB7)
v1pb8: J13.9, U13.18 (CB1)
v1pb9: J13.10, U13.19 (CB2)
v2pa0: J10.1, U12.2 (PA0)
v2pa1: J10.2, U12.3 (PA1)
v2pa2: J10.3, U12.4 (PA2)
v2pa3: J10.4, U12.5 (PA3)
v2pa4: J10.5, U12.6 (PA4)
v2pa5: J10.6, U12.7 (PA5)
v2pa6: J10.7, U12.8 (PA6); also elsewhere on the board
v2pa7: J10.8, U12.9 (PA7); also elsewhere on the board
v2pa8: J10.9, U12.40 (CA1)
v2pa9: J10.10, U12.39 (CA2)
v2pb0: J11.1, U12.10 (PB0); also elsewhere on the board
v2pb1: J11.2, U12.11 (PB1); also elsewhere on the board
v2pb2: J11.3, U12.12 (PB2); also elsewhere on the board
v2pb3: J11.4, U12.13 (PB3); also elsewhere on the board
v2pb4: J11.5, U12.14 (PB4); also elsewhere on the board
v2pb5: J11.6, U12.15 (PB5); also elsewhere on the board
v2pb6: J11.7, U12.16 (PB6); also elsewhere on the board
v2pb7: J11.8, U12.17 (PB7); also elsewhere on the board
v2pb8: J11.9, U12.18 (CB1)
v2pb9: J11.10, U12.19 (CB2)
~AIRQ: U5.26 (~IRQ); also elsewhere on the board
~CTS: J1.5, J46.2, U5.9 (~CTS), U6.2 (~RTS)
~IOCS: J44.2, J48.1, J50.2; also elsewhere on the board
~RES: U5.4 (~RES), U12.34 (~RES), U13.34 (~RES); also elsewhere on the board
~RTS: J1.1, J42.2, U5.8 (~RTS), U6.6 (~CTS)
~V1IRQ: U13.21 (~IRQ); also elsewhere on the board
~V2IRQ: U12.21 (~IRQ); also elsewhere on the board

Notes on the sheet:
DB6502 2>3
KrisOS 1>2
Jumpers
LCD
VIA 1 9000-900F
VIA2 8800-880F
ACIA 8200-820F

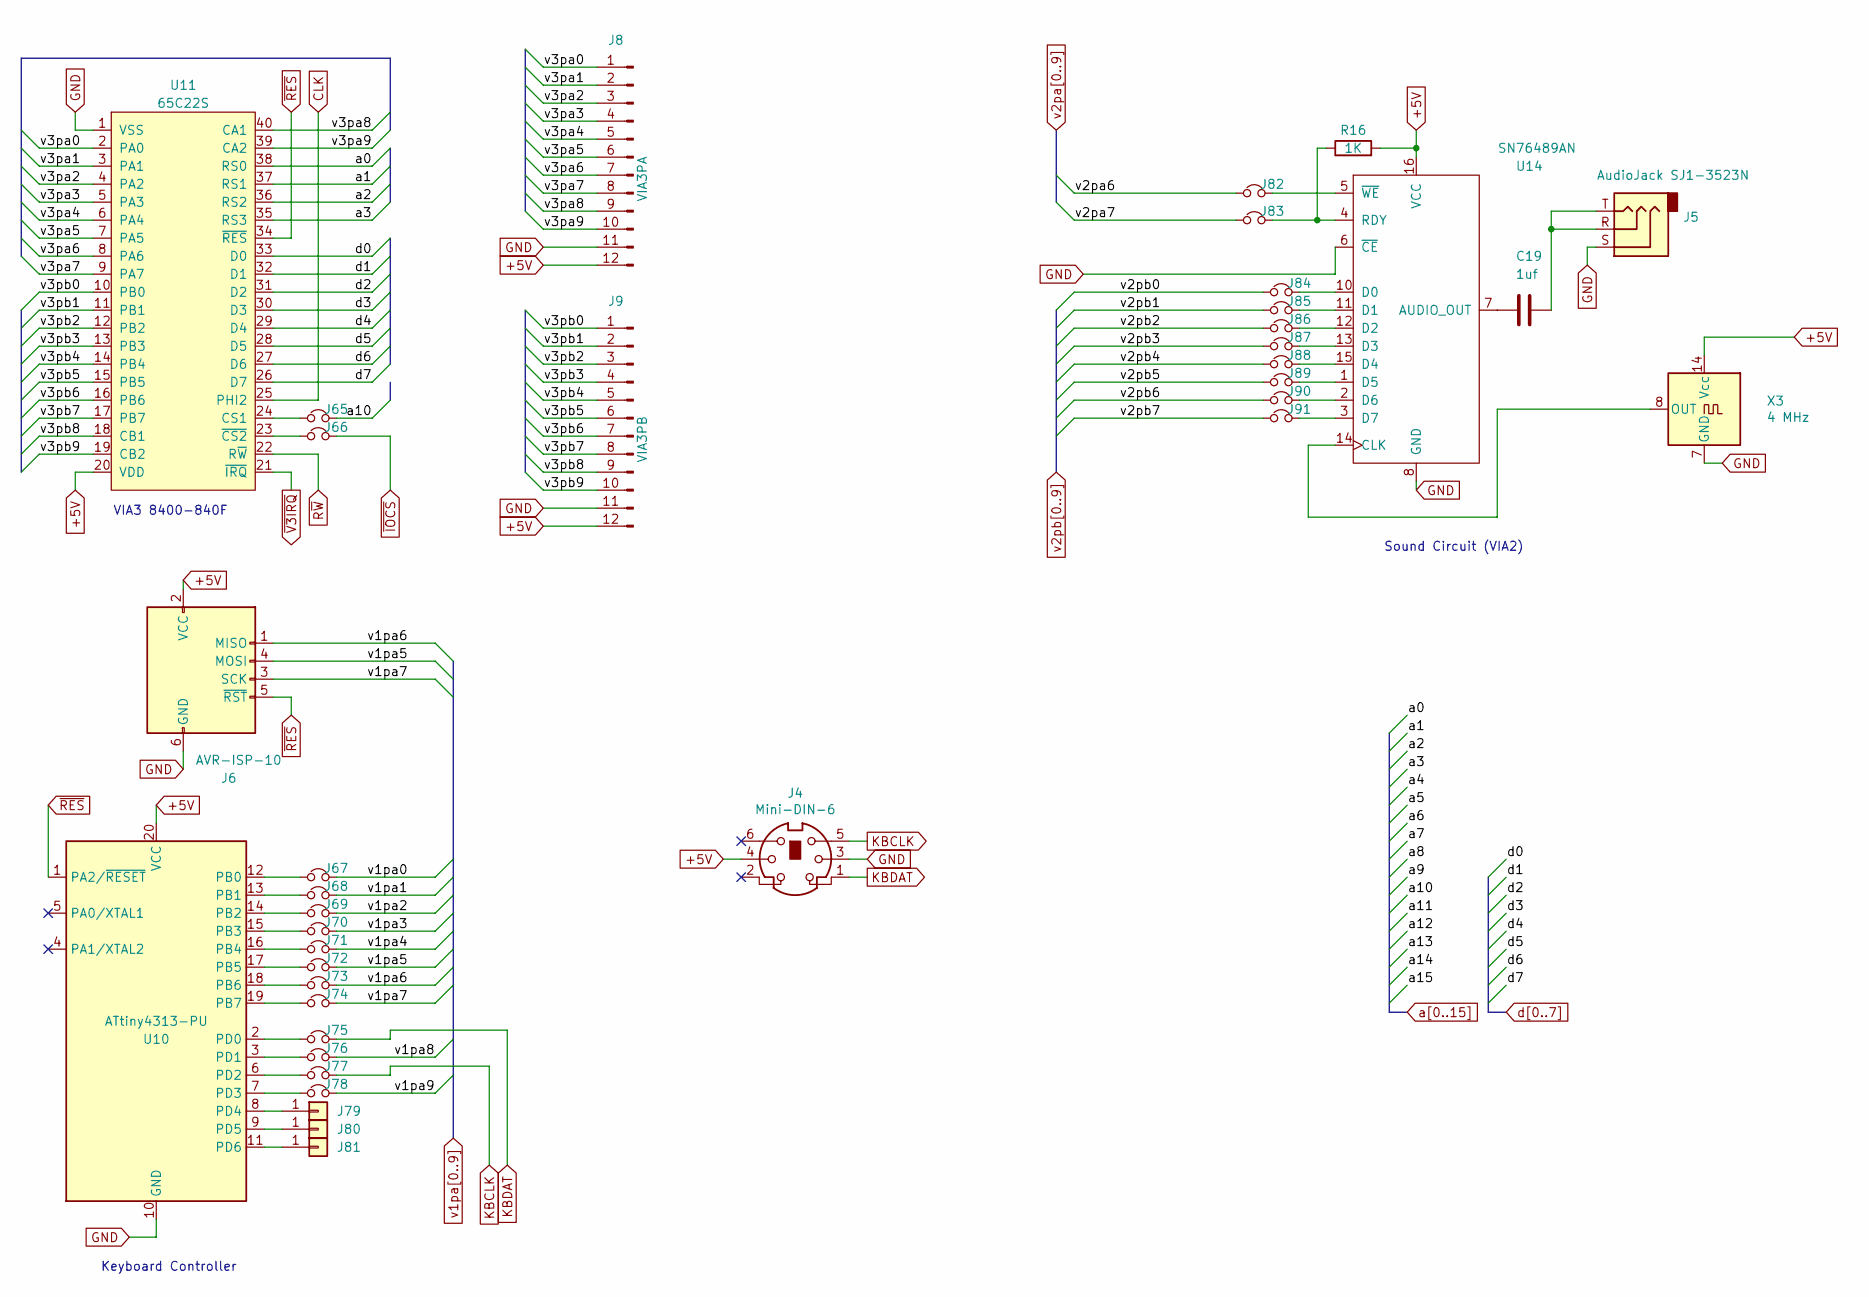
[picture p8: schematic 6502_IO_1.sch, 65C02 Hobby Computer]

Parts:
C19: 1uf; C_Disc_D3.4mm_W2.1mm_P2.50mm
J4: Mini-DIN-6; mini_din-6
J5: AudioJack SJ1-3523N; Jack_3.5mm_CUI_SJ1-3523N_Horizontal
J6: AVR-ISP-10; PinHeader_2x03_P2.54mm_Vertical
J8: VIA3PA; PinSocket_1x12_P2.54mm_Vertical
J9: VIA3PB; PinSocket_1x12_P2.54mm_Vertical
J65, J66, J67, J68, J69, J70, J71, J72, J73, J74, J75, J76, J77, J78, J82, J83, J84, J85, J86, J87, J88, J89, J90, J91: Jumper_NC_Small; PinHeader_1x02_P2.54mm_Vertical_Close
J79, J80, J81: Conn_01x01; PinHeader_1x01_P2.54mm_Vertical_Close
R16: 1K; R_Axial_DIN0207_L6.3mm_D2.5mm_P7.62mm_Horizontal
U10: ATtiny4313-PU; DIP-20_W7.62mm_Socket
U11: 65C22S; DIP-40_W15.24mm_Socket
U14: SN76489AN; DIP-16_W7.62mm_Socket
X3: 4 MHz; Oscillator_DIP-14

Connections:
+5V: J4.4, J6.2 (VCC), J8.12, J9.12, R16.2, U10.20 (VCC), U11.20 (VDD), U14.16 (VCC), X3.14 (Vcc); also elsewhere on the board
/6502 Peripherals 1/v3pa0: J8.1, U11.2 (PA0)
/6502 Peripherals 1/v3pa1: J8.2, U11.3 (PA1)
/6502 Peripherals 1/v3pa2: J8.3, U11.4 (PA2)
/6502 Peripherals 1/v3pa3: J8.4, U11.5 (PA3)
/6502 Peripherals 1/v3pa4: J8.5, U11.6 (PA4)
/6502 Peripherals 1/v3pa5: J8.6, U11.7 (PA5)
/6502 Peripherals 1/v3pa6: J8.7, U11.8 (PA6)
/6502 Peripherals 1/v3pa7: J8.8, U11.9 (PA7)
/6502 Peripherals 1/v3pa8: J8.9, U11.40 (CA1)
/6502 Peripherals 1/v3pa9: J8.10, U11.39 (CA2)
/6502 Peripherals 1/v3pb0: J9.1, U11.10 (PB0)
/6502 Peripherals 1/v3pb1: J9.2, U11.11 (PB1)
/6502 Peripherals 1/v3pb2: J9.3, U11.12 (PB2)
/6502 Peripherals 1/v3pb3: J9.4, U11.13 (PB3)
/6502 Peripherals 1/v3pb4: J9.5, U11.14 (PB4)
/6502 Peripherals 1/v3pb5: J9.6, U11.15 (PB5)
/6502 Peripherals 1/v3pb6: J9.7, U11.16 (PB6)
/6502 Peripherals 1/v3pb7: J9.8, U11.17 (PB7)
/6502 Peripherals 1/v3pb8: J9.9, U11.18 (CB1)
/6502 Peripherals 1/v3pb9: J9.10, U11.19 (CB2)
CLK: U11.25 (PHI2); also elsewhere on the board
GND: J4.3, J5.S, J6.6 (GND), J8.11, J9.11, U10.10 (GND), U11.1 (VSS), U14.6 (~CE), U14.8 (GND), X3.7 (GND); also elsewhere on the board
KBCLK: J4.5, J77.2
KBDAT: J4.1, J75.2
unnamed: C19.1, J5.R, J5.T
unnamed: C19.2, U14.7 (AUDIO_OUT)
unnamed: J65.1, U11.24 (CS1)
unnamed: J66.1, U11.23 (~CS2)
unnamed: J67.1, U10.12 (PB0)
unnamed: J68.1, U10.13 (PB1)
unnamed: J69.1, U10.14 (PB2)
unnamed: J70.1, U10.15 (PB3)
unnamed: J71.1, U10.16 (PB4)
unnamed: J72.1, U10.17 (PB5)
unnamed: J73.1, U10.18 (PB6)
unnamed: J74.1, U10.19 (PB7)
unnamed: J75.1, U10.2 (PD0)
unnamed: J76.1, U10.3 (PD1)
unnamed: J77.1, U10.6 (PD2)
unnamed: J78.1, U10.7 (PD3)
unnamed: J79.1, U10.8 (PD4)
unnamed: J80.1, U10.9 (PD5)
unnamed: J81.1, U10.11 (PD6)
unnamed: J82.2, U14.5 (~WE)
unnamed: J83.2, R16.1, U14.4 (RDY)
unnamed: J84.2, U14.10 (D0)
unnamed: J85.2, U14.11 (D1)
unnamed: J86.2, U14.12 (D2)
unnamed: J87.2, U14.13 (D3)
unnamed: J88.2, U14.15 (D4)
unnamed: J89.2, U14.1 (D5)
unnamed: J90.2, U14.2 (D6)
unnamed: J91.2, U14.3 (D7)
unnamed: U14.14 (CLK), X3.8 (OUT)
R~W: U11.22 (R~W); also elsewhere on the board
a0: U11.38 (RS0); also elsewhere on the board
a1: U11.37 (RS1); also elsewhere on the board
a2: U11.36 (RS2); also elsewhere on the board
a3: U11.35 (RS3); also elsewhere on the board
a10: J65.2; also elsewhere on the board
d0: U11.33 (D0); also elsewhere on the board
d1: U11.32 (D1); also elsewhere on the board
d2: U11.31 (D2); also elsewhere on the board
d3: U11.30 (D3); also elsewhere on the board
d4: U11.29 (D4); also elsewhere on the board
d5: U11.28 (D5); also elsewhere on the board
d6: U11.27 (D6); also elsewhere on the board
d7: U11.26 (D7); also elsewhere on the board
v1pa0: J67.2; also elsewhere on the board
v1pa1: J68.2; also elsewhere on the board
v1pa2: J69.2; also elsewhere on the board
v1pa3: J70.2; also elsewhere on the board
v1pa4: J71.2; also elsewhere on the board
v1pa5: J6.4 (MOSI), J72.2; also elsewhere on the board
v1pa6: J6.1 (MISO), J73.2; also elsewhere on the board
v1pa7: J6.3 (SCK), J74.2; also elsewhere on the board
v1pa8: J76.2; also elsewhere on the board
v1pa9: J78.2; also elsewhere on the board
v2pa6: J82.1; also elsewhere on the board
v2pa7: J83.1; also elsewhere on the board
v2pb0: J84.1; also elsewhere on the board
v2pb1: J85.1; also elsewhere on the board
v2pb2: J86.1; also elsewhere on the board
v2pb3: J87.1; also elsewhere on the board
v2pb4: J88.1; also elsewhere on the board
v2pb5: J89.1; also elsewhere on the board
v2pb6: J90.1; also elsewhere on the board
v2pb7: J91.1; also elsewhere on the board
~IOCS: J66.2; also elsewhere on the board
~RES: J6.5 (~RST), U10.1 (PA2/~RESET), U11.34 (~RES); also elsewhere on the board
~V3IRQ: U11.21 (~IRQ); also elsewhere on the board

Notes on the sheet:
Keyboard Controller
VIA3 8400-840F
Sound Circuit (VIA2)

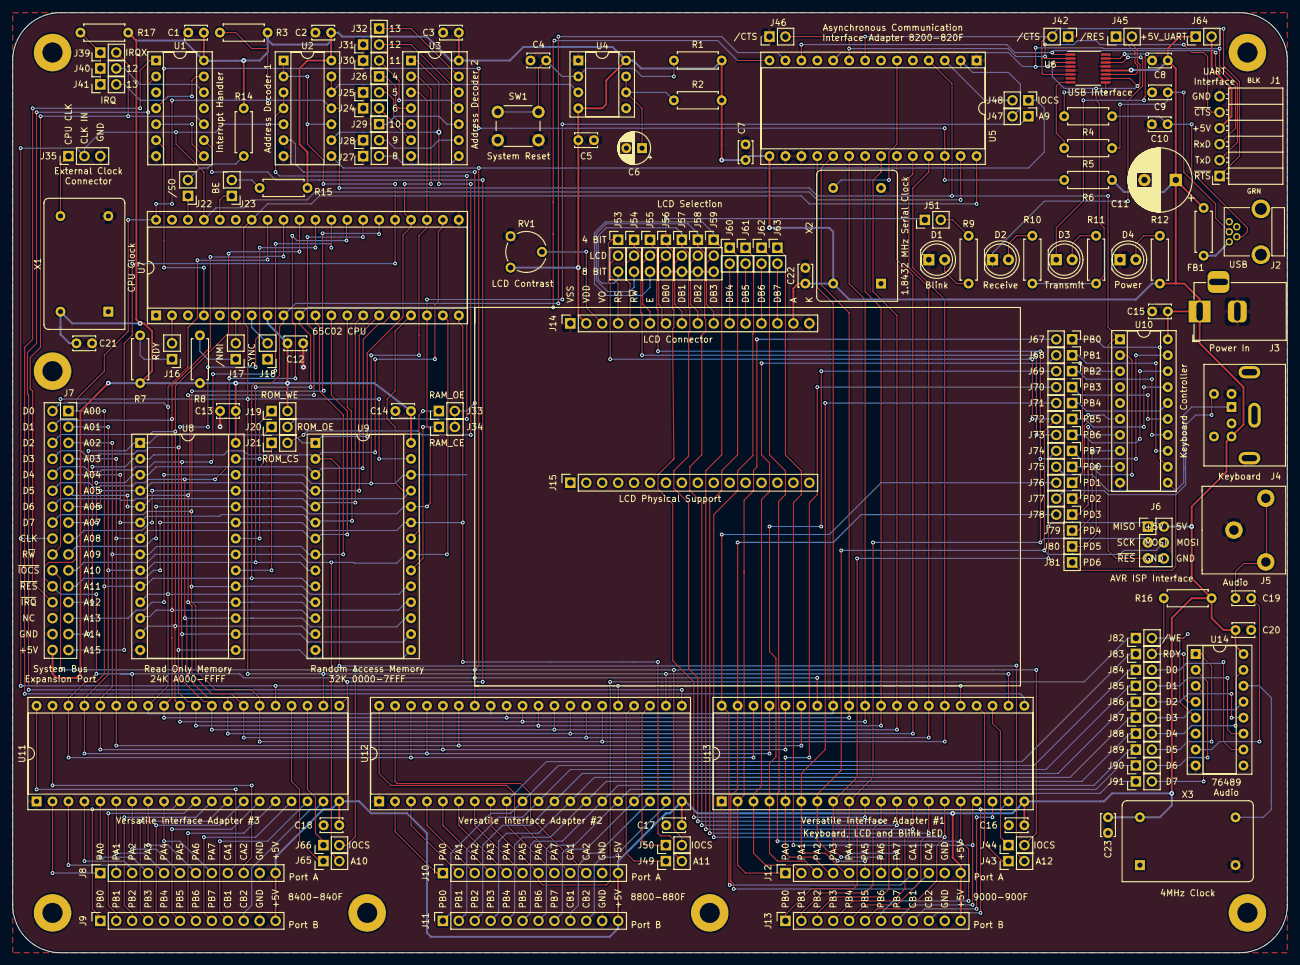
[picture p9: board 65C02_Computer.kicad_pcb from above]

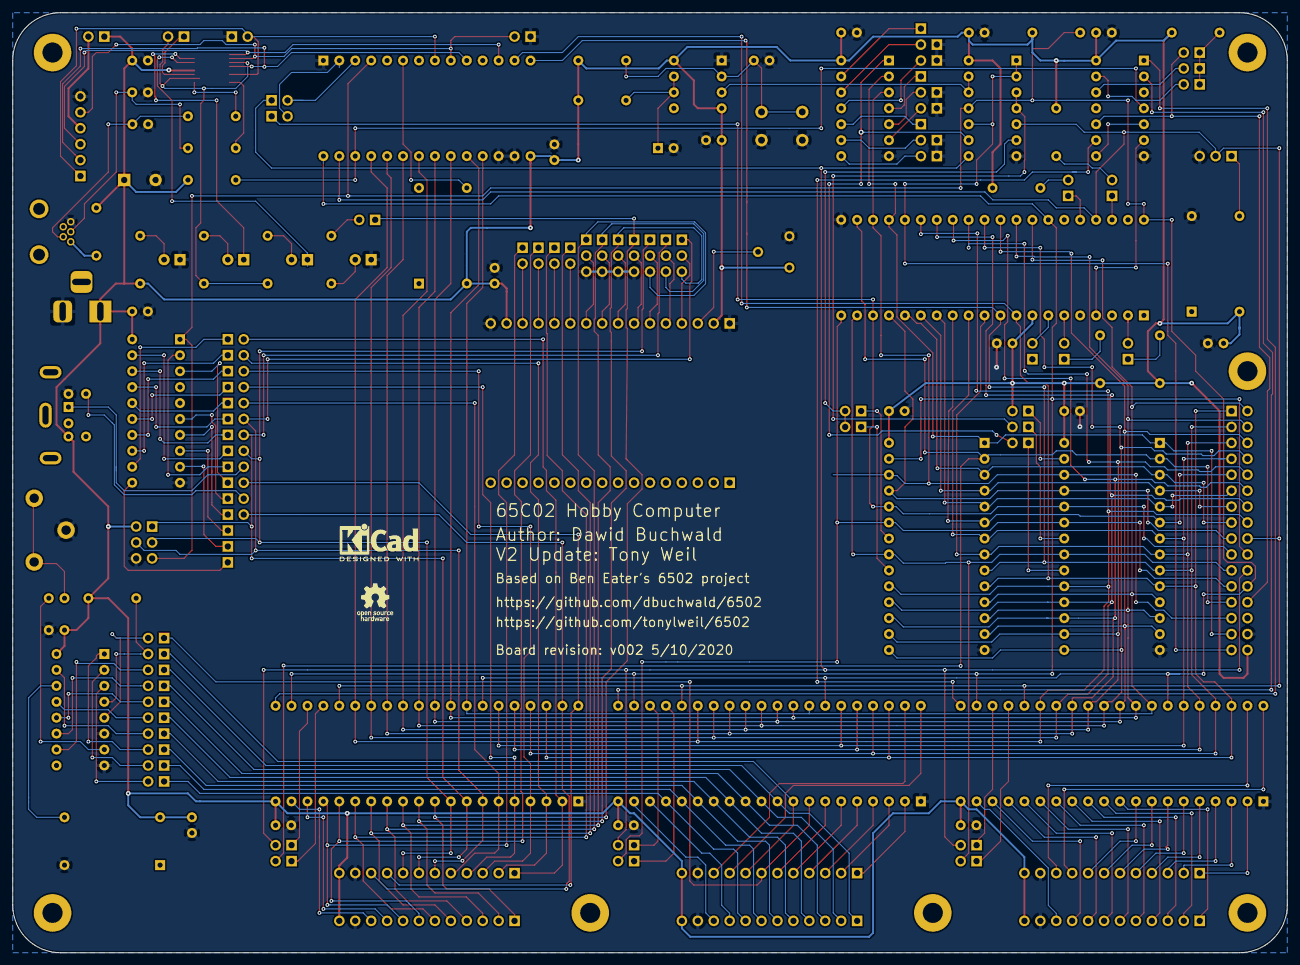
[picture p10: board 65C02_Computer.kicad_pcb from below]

Board: 2 copper layers, 203.2 x 149.9 mm, 159 parts (2 on the bottom side), 200 nets.

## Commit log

2020-05-10 Updated schematics and board files to V002
    [6502_IO.sch, 6502_IO_1.sch, 65C02_Computer.kicad_pcb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]
2020-05-10 Update files to v002
    [6502_IO.sch, 6502_IO_1.sch, 65C02_Computer.kicad_pcb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]
